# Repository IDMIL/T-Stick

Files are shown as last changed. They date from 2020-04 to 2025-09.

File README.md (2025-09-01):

# T-Stick Digital Musical Instrument (DMI)

The T-Stick is a DMI conceived by Joseph Malloch and D. Andrew Stewart at the Input Devices and Music Interaction Laboratory (IDMIL) at McGill University. It has been in development since 2006, has a relatively long history for a DMI, has multiple versions, several expert performers, and has an associated repertoire. More than 20 copies have been built unintended for commercial use. Nevertheless, it has been adopted by expert performers and composers as part of their musical practice including D. Andrew Stewart (Soprano user) and Fernando Rocha (Tenor user). It has appeared in dozens of public appearances in countries such as Canada, USA, Brazil, Italy, Norway, and Portugal.

This repository hosts up to date firmware for the T-Stick instruments currently at the IDMIL. The T-Stick Documentation data contains technical information as well as guides for how to use the T-Stick 4G/5G.

T-Stick Documentation: https://idmil.github.io/tstick-docs/

## Documentation:

[T-Stick connection guide for T-Stick 4G/5G](https://idmil.github.io/tstick-docs/designs/tstick-5gw/connection-guide/)

[T-Stick firmware upgrade guide](https://idmil.github.io/tstick-docs/designs/tstick-5gw/flashing-guide/)

[How to build a T-Stick 4G](https://idmil.github.io/tstick-docs/designs/tstick-5gw/build-guide/)

[How to build a T-Stick 5G](https://idmil.github.io/tstick-docs/designs/tstick-5gw/build-guide/)

[OSC sensor data list for T-Stick 4G/5G](https://idmil.github.io/tstick-docs/designs/tstick-5gw/specs_5gw_trill/#osc-signal-namespace)

## Instruments:

As of October 2021, there are over 20 instruments built at [IDMIL](http://www.idmil.org) and in use by several composers and performers:

- 01 T-Stick Tenor (2G)
- 06 T-Stick Sopranos (2G, 2GX, 2G-IMU)
- 01 T-Stick Sopranino (2G)
- 20+ wireless T-Stick Sopraninos (2G, 2GW, 3G, 4G, 5G)

## Project info:

Project webpage at IDMIL: http://www.idmil.org/project/the-t-stick/ \
T-Stick Documentation: https://idmil.github.io/tstick-docs/ \
Official repository: https://github.com/IDMIL/TStick

IDMIL - Input Devices and Music Interaction Laboratory - http://www.idmil.org/ \
CIRMMT - Centre for Interdisciplinary Research in Music Media and Technology - http://www.cirmmt.org/ \
Schulich School of Music - McGill University

## Licensing

The code in this project is licensed under the MIT license.

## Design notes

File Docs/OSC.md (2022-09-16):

# T-Stick OSC sensor data

## firmware 220916

#### (Replace XXX for the T-Stick ID number)

## Raw data

/TStick_XXX/raw/capsense, i..., 0--255, ... (1 int per 8 capacitive stripes -- 8 bits)

/TStick_XXX/raw/fsr, i, 0--4095

/TStick_XXX/raw/accl, fff, +/-24 (floats)

/TStick_XXX/raw/gyro, fff, +/-42 (floats)

/TStick_XXX/raw/magn, iii, +/-0.001 (floats)

## Instrument data

/TStick_XXX/instrument/button/count, i, 0--i

/TStick_XXX/instrument/button/tap, i, 0 or 1

/TStick_XXX/instrument/button/dtap, i, 0 or 1

/TStick_XXX/instrument/button/ttap, i, 0 or 1

/TStick_XXX/orientation, ffff, ?, ? ,? ,?

/TStick_XXX/instrument/ypr, fff, +/-180, +/-90 ,+/-180 (degrees)

/TStick_XXX/instrument/touch/all, f, 0--1

/TStick_XXX/instrument/touch/top, f, 0--1

/TStick_XXX/instrument/touch/middle, f, 0--1

/TStick_XXX/instrument/touch/bottom, f, 0--1

/TStick_XXX/instrument/brush, f, 0--? (~cm/s)

/TStick_XXX/instrument/multibrush, ffff, 0--? (~cm/s)

/TStick_XXX/instrument/rub, f, 0--? (~cm/s)

/TStick_XXX/instrument/multirub, ffff, 0--? (~cm/s)

/TStick_XXX/instrument/shakexyz, fff, 0--?

/TStick_XXX/instrument/jabxyz, fff, 0--?

/TStick_XXX/battery

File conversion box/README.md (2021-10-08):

# T-Stick Conversion Box - Building recipe - Rpi 2B and 3B+

Under Raspbian Lite

## Prepare the OS

- Flash the latest Prynth image (https://prynth.github.io/create/downloads.html)
- Add ssh file to Boot partition: `touch ssh`
- Add wpa_supplicant.conf to file to Boot partition: `vim wpa_supplicant.conf`. File contents:

```bash
ctrl_interface=DIR=/var/run/wpa_supplicant GROUP=netdev
update_config=1
country=US

network={
     ssid="Your network name/SSID"
     psk="Your WPA/WPA2 security key"
     key_mgmt=WPA-PSK
}
```

- Open Prynth software settings at `http://raspberrypi.local:3000/system` and change hostname to match the converted T-Stick  
- SSH, change password, hostname, set country, expand file system (raspi-config)

## Update

```bash
sudo apt-get -y update
sudo apt-get -y dist-upgrade
```

## Install liblo

```bash
sudo apt-get remove -y liblo-dev
mkdir ~/sources
cd ~/sources
git clone https://github.com/radarsat1/liblo.git
cd liblo
sudo apt-get install -y vim autoconf libtool automake
./autogen.sh
make
sudo make install
```

## Install Libmapper

```bash
sudo apt-get install python-dev swig
cd ~/sources
git clone https://github.com/libmapper/libmapper.git
cd libmapper
./autogen.sh
echo 'export LD_LIBRARY_PATH=$LD_LIBRARY_PATH:/usr/local/lib' >> ~/.bashrc
make
sudo make install
```

## Install Webmapper

```bash
pip install netifaces
cd ~/sources
git clone https://github.com/libmapper/webmapper.git
cp ~/sources/libmapper/swig/_mapper.so ~/sources/webmapper
cp ~/sources/libmapper/swig/mapper.py ~/sources/webmapper
cd webmapper/
```

- To run Webmapper: ./webmapper.py

## Install Python 3.7.3

```bash
sudo apt-get install -y build-essential tk-dev libncurses5-dev libncursesw5-dev libreadline6-dev libdb5.3-dev libgdbm-dev libsqlite3-dev libssl-dev libbz2-dev libexpat1-dev liblzma-dev zlib1g-dev libffi-dev apt-show-versions
cd ~/sources
wget https://www.python.org/ftp/python/3.7.3/Python-3.7.3.tgz
tar -zxvf Python-3.7.3.tgz
cd Python-3.7.3/
./configure --enable-optimizations
make -j4
make test
sudo make install
```

Reboot

## Create python application to read serial port and send OSC messages

- Install packages:

```bash
cd ~
sudo apt-get install -y python3-pip python-pip setserial
sudo pip3 install python-osc pyserial apscheduler bitstring netifaces
pip install pyserial apscheduler bitstring pyOSC netifaces oscpy
mkdir tstick
```

- Create code:

```bash
cat <<- "EOF" | sudo tee ~/tstick/tstick.py
# Python code to convert T-Stick serial port messages to OSC
# Author: Edu Meneses (IDMIL, 2019)

import sys
import serial
import collections
from apscheduler.schedulers.background import BackgroundScheduler
from bitstring import BitArray
import netifaces as ni

import argparse
from pythonosc import osc_message_builder
from pythonosc import udp_client
from pythonosc.dispatcher import Dispatcher

from pythonosc.osc_server import AsyncIOOSCUDPServer
import asyncio

# parse argument to set OSC to send/receive T-Stick data
parser = argparse.ArgumentParser(
    description='Convert T-Stick serial port messages into OSC messages.',
    formatter_class=argparse.ArgumentDefaultsHelpFormatter)
parser.add_argument("--serialport", "-s", default="/dev/ttyUSB0",
                    metavar='', help="The T-Stick's serial port")
parser.add_argument("--ip", "-i", default="192.168.0.1",
                    metavar='', help="The ip of the OSC server")
parser.add_argument("--port", "-p", type=int, default=8000,
                    metavar='', help="The port the OSC server is listening on")
parser.add_argument("--networkinterface", "-n", default="wlan0",
                    metavar='', help="The interface connected to the network")
parser.add_argument("--listenport", "-l", type=int, default=8888,
                    metavar='', help="The port this machine is listening on")
args = parser.parse_args()

# set listening ip to receive OSC messages
ni.ifaddresses(args.networkinterface)
local_ip = ni.ifaddresses(args.networkinterface)[ni.AF_INET][0]['addr']

# Opening T-Stick serial port
tstick = serial.Serial(args.serialport, 115200, dsrdtr=1)

# checking system byteorder
byteorder = sys.byteorder

# creating global variable to define T-Stick mapping
tstick_id = 0

dispatcher = Dispatcher()

client_OSC = udp_client.SimpleUDPClient(args.ip, args.port)

def resend(address, *args):
    tstick.write(args)

def heartbeat():
    tstick.write('s'.encode('utf-8'))

async def receive_serial():
    flag = False
    msg = []
    while True:
        byte = int.from_bytes(tstick.read(), byteorder)
        if not flag:
            if byte == 100:
                get_tstick_id(*msg)
                if(tstick_id == 173):
                    sort_and_send_173(*msg)
                elif(tstick_id == 10 or
                     tstick_id == 12 or
                     tstick_id == 24 or
                     tstick_id == 171):
                    sort_and_send_2G(*msg)
                elif(tstick_id == 15):
                    sort_and_send_2GX(*msg)
                msg.clear()
            elif byte == 101:
                flag = True
            else:
                msg.append(byte)
        else:
            msg.append(byte)
            flag = False
        await asyncio.sleep(0)

# 'convert' 10 bits
def bit_conversion(byte1, byte2):
    return (byte1 * 256) + byte2

# T-stick 16 bit conversion IMU
def bit_ext_conversion(byte1, byte2):
    bin_or = (byte1 * 256) | byte2
    return bin_or - (65535 * (bin_or > 32767))

def get_tstick_id(*msg):
    if msg[0] == 0:
        if len(msg) < 3:
            return 0
        global tstick_id
        tstick_id = bit_conversion(msg[1], msg[2])
        firmware = bit_conversion(msg[3], msg[4])
        info_list = [tstick_id, firmware]
        if len(msg) > 5:
            for i in msg[5:]:
                info_list.append(i)
        client_OSC.send_message("/information", info_list)
        return tstick_id

# route T-Stick messages for T-Stick #173
def sort_and_send_173(*msg):
    if msg[0] == 0:
        pass
    elif msg[0] == 1:
        rawcapsense = msg[1:]
        client_OSC.send_message("/rawcapsense", rawcapsense)
        # capsense_bits = cook_touch_soprano(*rawcapsense)
    elif msg[0] == 2:
        accel_x = bit_ext_conversion(msg[1], msg[2])
        accel_y = bit_ext_conversion(msg[3], msg[4])
        accel_z = bit_ext_conversion(msg[5], msg[6])
        gyro_x = bit_ext_conversion(msg[7], msg[8])
        gyro_y = bit_ext_conversion(msg[9], msg[10])
        gyro_z = bit_ext_conversion(msg[11], msg[12])
        pressure = bit_ext_conversion(msg[13], msg[14])
        piezo = bit_ext_conversion(msg[15], msg[16])
        client_OSC.send_message("/rawaccel", [accel_x, accel_y, accel_z])
        client_OSC.send_message("/rawgyro", [gyro_x, gyro_y, gyro_z])
        client_OSC.send_message("/rawpressure", pressure)
        client_OSC.send_message("/rawpiezo", piezo)
    elif msg[0] == 3:
        mag_x = bit_ext_conversion(msg[1], msg[2])
        mag_y = bit_ext_conversion(msg[3], msg[4])
        mag_z = bit_ext_conversion(msg[5], msg[6])
        client_OSC.send_message("/rawmag", [mag_x, mag_y, mag_z])
    elif msg[0] == 4:
        return 0

# route T-Stick messages for T-Stick 2G series: 010, 012, 024, 171
def sort_and_send_2G(*msg):
    if msg[0] == 0:
        pass
    elif msg[0] == 1:
        rawcapsense = msg[1:]
        client_OSC.send_message("/rawcapsense", rawcapsense)
        # capsense_bits = cook_touch_soprano(*rawcapsense)
    elif msg[0] == 2:
        rawjab = msg[1:]
        client_OSC.send_message("/rawjab", rawjab)
    elif msg[0] == 3:
        rawtap = msg[1:]
        client_OSC.send_message("/rawtap", rawtap)
    elif msg[0] == 4:
        accel_x = bit_conversion(msg[1], msg[2])
        accel_y = bit_conversion(msg[3], msg[4])
        accel_z = bit_conversion(msg[5], msg[6])
        pressure = bit_conversion(msg[7], msg[8])
        piezo = bit_conversion(msg[9], msg[10])
        client_OSC.send_message("/rawaccel", [accel_x, accel_y, accel_z])
        client_OSC.send_message("/rawpressure", pressure)
        client_OSC.send_message("/rawpiezo", piezo)

# route T-Stick messages for T-Stick #015
def sort_and_send_2GX(*msg):
    if msg[0] == 0:
        pass
    elif msg[0] == 1:
        rawcapsense = msg[1:]
        client_OSC.send_message("/rawcapsense", rawcapsense)
        # capsense_bits = cook_touch_soprano(*rawcapsense)
    elif msg[0] == 2:
        rawjab = msg[1:]
        client_OSC.send_message("/rawjab", rawjab)
    elif msg[0] == 3:
        rawtap = msg[1:]
        client_OSC.send_message("/rawtap", rawtap)
    elif msg[0] == 4:
        accel_x = bit_conversion(msg[1], msg[2])
        accel_y = bit_conversion(msg[3], msg[4])
        accel_z = bit_conversion(msg[5], msg[6])
        pressure = bit_conversion(msg[7], msg[8])
        piezo = bit_conversion(msg[9], msg[10])
        airpressure = bit_conversion(msg[11], msg[12])
        tstick_range = bit_conversion(msg[13], msg[14])
        ldr1 = bit_conversion(msg[15], msg[16])
        ldr2 = bit_conversion(msg[17], msg[18])
        client_OSC.send_message("/rawaccel", [accel_x, accel_y, accel_z])
        client_OSC.send_message("/rawpressure", pressure)
        client_OSC.send_message("/rawpiezo", piezo)
        client_OSC.send_message("/rawairpressure", airpressure)
        client_OSC.send_message("/rawrange", tstick_range)
        client_OSC.send_message("/rawldr1", ldr1)
        client_OSC.send_message("/rawldr2", ldr2)

# make bit list - 1 per cap stripe
def cook_touch_soprano(*bytes):
    byte_list = ""
    for byte in bytes:
        byte_list = byte_list + format(byte, '08b')
    return list(byte_list)

# setting heartbeat to run every second
def tstick_wakeup():
    scheduler = BackgroundScheduler()
    scheduler.add_job(heartbeat, 'interval', seconds=1)
    scheduler.start()

async def init_main():
    # Create datagram endpoint and start serving
    server_OSC = AsyncIOOSCUDPServer(
        (local_ip, args.listenport), dispatcher, asyncio.get_event_loop())

    transport, protocol = await server_OSC.create_serve_endpoint()

    dispatcher.map("/status", resend)

    tstick_wakeup()

    await receive_serial()

    transport.close()  # Clean up serve endpoint

    sys.exit()

asyncio.run(init_main())  # Init and enter main loop of program

EOF

```
Set the code to load at boot:

```bash
cat <<- "EOF" | sudo tee /lib/systemd/system/tstick.service
[Unit]
Description=T-Stick serial port to OSC conversion

[Service]
ExecStart=/usr/bin/python3 /home/pi/tstick/tstick.py
#User=pi

[Install]
WantedBy=multi-user.target
EOF

```

```bash
sudo systemctl daemon-reload &&\
sudo systemctl enable hardwarecontrol.service
```

Old, unnecessary packages are removed after the system update with the following commands:

```bash
sudo apt-get autoremove
sudo apt-get autoclean
```

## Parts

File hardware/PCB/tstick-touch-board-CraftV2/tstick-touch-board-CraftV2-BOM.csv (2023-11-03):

Manufacturer | Manufacturer Part # | Qty | Description Value Pkg | Reference(s)
Molex | 54132-3262 | 1 | 32 Position FFC, FPC Connector Contacts, Bottom 0.020" (0.50mm) Surface Mount, Right Angle | J1
JST Sales America Inc. | BM04B-SRSS-TB | 4 | Connector Header Surface Mount, Right Angle 4 position 0.039" (1.00mm) | I2C1,I2C2,INT1,INT2

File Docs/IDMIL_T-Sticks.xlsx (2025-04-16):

Update: | 2025-03-11
ID | Model | Generation | FirmWare | Last Review | Pictures |  |  | Comments | Status
191 | Sopranino |  |  |  |  |  |  |  | IDMIL
193 | Sopranino | 4 | TBC |  | #VALUE! | #VALUE! | #VALUE! | turns on as 001 flow of OSC messages very slow ~1/s button and switch don't seem to do anything works only when plugged | Location unknown
194 | Sopranino | 4 | TBC | 2024-08-31 | #VALUE! | #VALUE! | #VALUE! | Unclear which if for on/off or charging (switch or button) No light turning on, no OSC message received hear a loose piece inside | Location unknown
308 | Sopranino | 4 | TBC | 2024-08-31 | #VALUE! | #VALUE! | #VALUE! | Several capsense tend to stay stuck Capsense # 16 never turn on shake values can go from ~0.8 to > 200 jabs triggered at the slightest movement | Location unknown
311 | Sopranino | 4 | TBC |  | #VALUE! | #VALUE! | #VALUE! |  | IDMIL
315 | Soprano | ? |  |  |  |  |  | USB connection is loose need reflash? Needs to be plugged to work | IDMIL
500 | Sopranino | 5 |  |  |  |  |  | button doesn't work Oren's haptic T-Stick? | IDMIL
514 | Sopranino | 5 |  |  | #VALUE! | #VALUE! |  | Turns off for ~5s when strongly shaken… Needs maintenance | IDMIL
516 |  |  |  |  |  |  |  | FSR doesn't work capsense values up to 1000+??? | IDMIL
517 | Sopranino | 5 |  |  |  |  |  | Don't know if it can be glued back | Borrowed by GM
555 | Sopranino | 5 |  |  |  |  |  | seems ok… | IDMIL
566 | Sopranino | 5 |  |  |  |  |  | Capsense doesn't work | Location unknown
569 | Sopranino | 5 |  |  |  |  |  | doesn't turn on | IDMIL
588 |  |  |  |  |  |  |  | unlabeled prototype | IDMIL

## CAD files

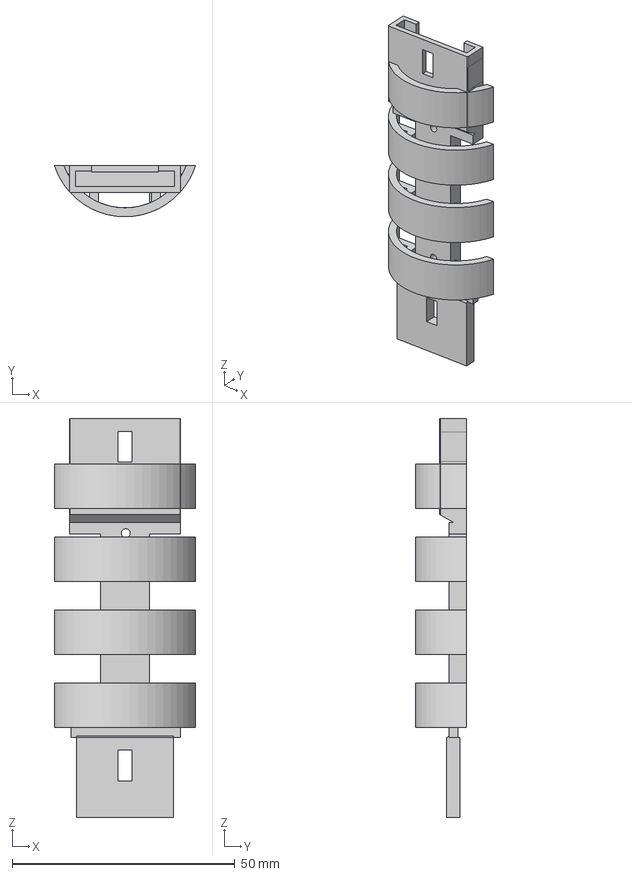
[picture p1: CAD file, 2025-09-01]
3D_printing/T-Stick 4GW/bed_capsense.stp
31.7 x 11.5 x 89.5 mm
battery_cap
esp_cap
capsense_bed+arcs
dummy_bed+arcs x 2
tinypico + imu_bed+arcs (1)
poles
small pin (1)

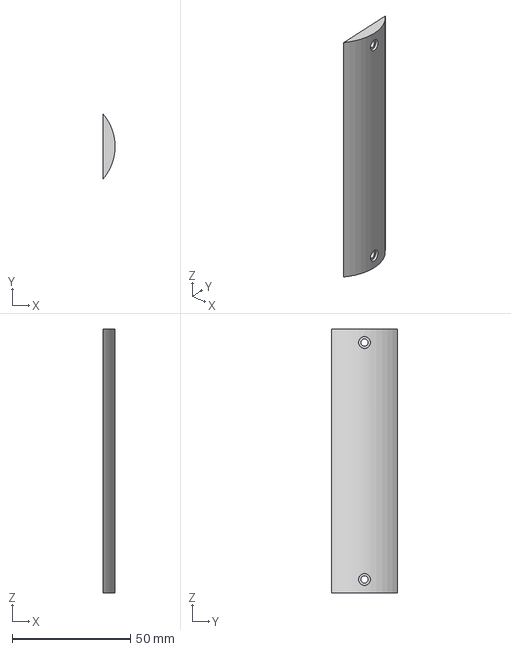
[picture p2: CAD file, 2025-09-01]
3D_printing/T-Stick 5GW/touch-board-door.step
5.19 x 27.7 x 111.4 mm

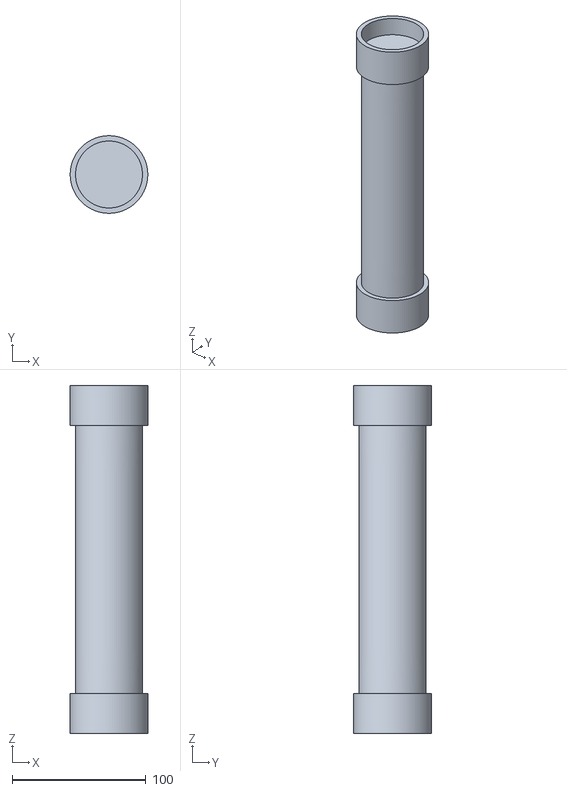
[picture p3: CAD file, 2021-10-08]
Sopranino/2GW/FW19111/Configuration/T-Stick.stl
58.0 x 58.0 x 260.0

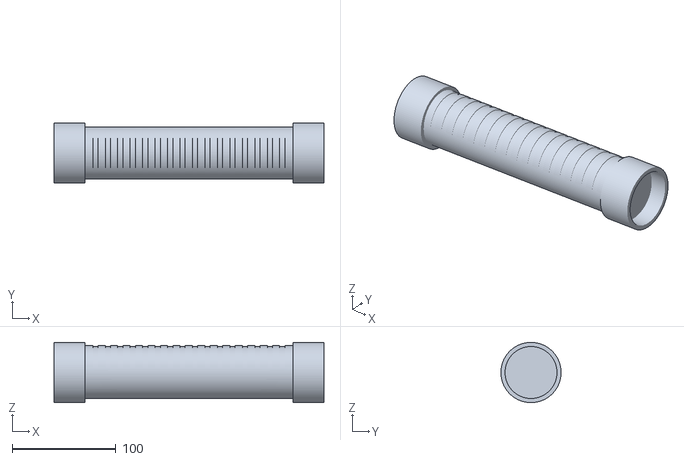
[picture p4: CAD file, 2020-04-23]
Test_config/PD/T-Stick.stl
260.0 x 58.0 x 58.0

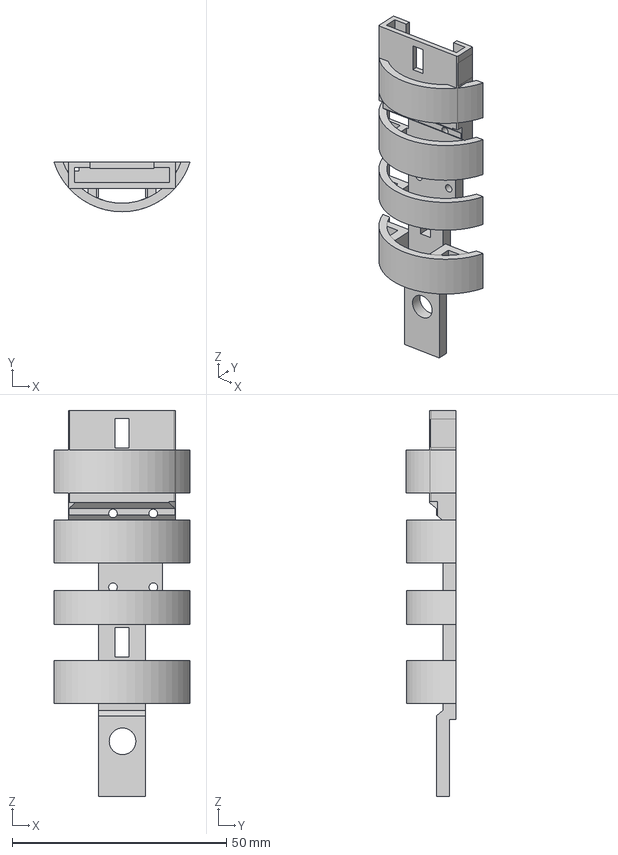
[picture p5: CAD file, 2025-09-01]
3D_printing/T-Stick 4GW/bed_tinypico_microUSB.stp
31.7 x 11.5 x 90.0 mm
battery_cap
esp_cap
capsense_bed+arcs
dummy_bed+arcs x 2
tinypico + imu_bed+arcs (1)
poles
small pin (1)

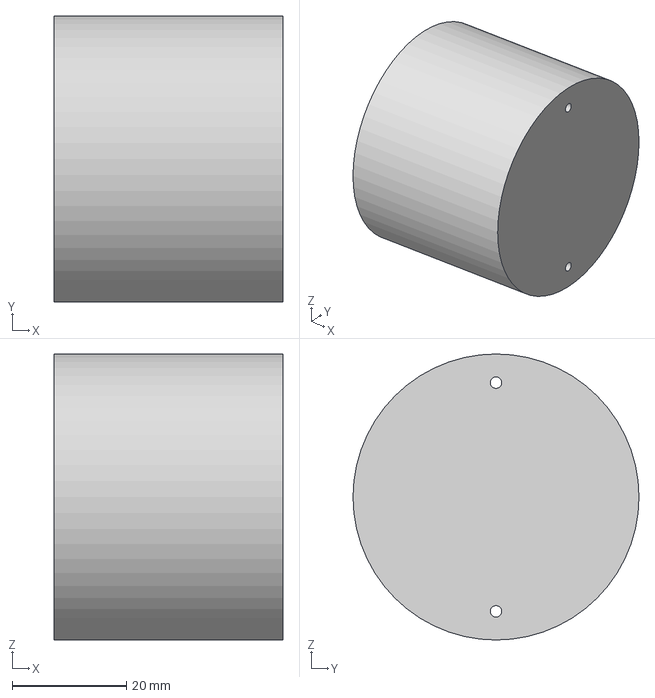
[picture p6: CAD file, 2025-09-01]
3D_printing/T-Stick 5GW/liion-capcloser.step
40.0 x 50.0 x 50.0 mm

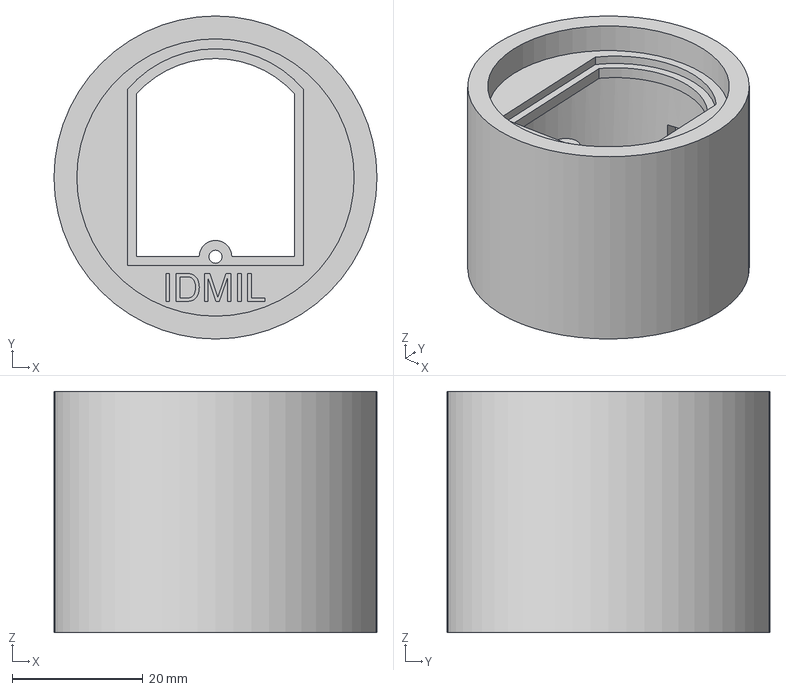
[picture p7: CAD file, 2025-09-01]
3D_printing/T-Stick 4GW/cap_battery_body.stp
49.5 x 49.5 x 37.0 mm
battery_cap
esp_cap
capsense_bed+arcs
dummy_bed+arcs x 2
tinypico + imu_bed+arcs (1)
poles
small pin (1)

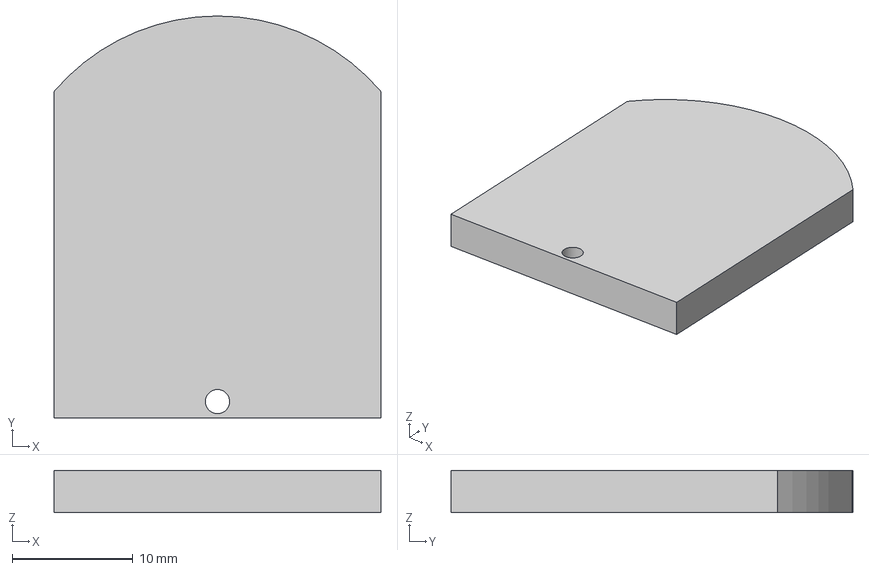
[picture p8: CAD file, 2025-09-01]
3D_printing/T-Stick 4GW/cap_battery_cover.stp
27.0 x 33.2 x 3.50 mm
battery_cap
esp_cap
capsense_bed+arcs
dummy_bed+arcs x 2
tinypico + imu_bed+arcs (1)
poles
small pin (1)

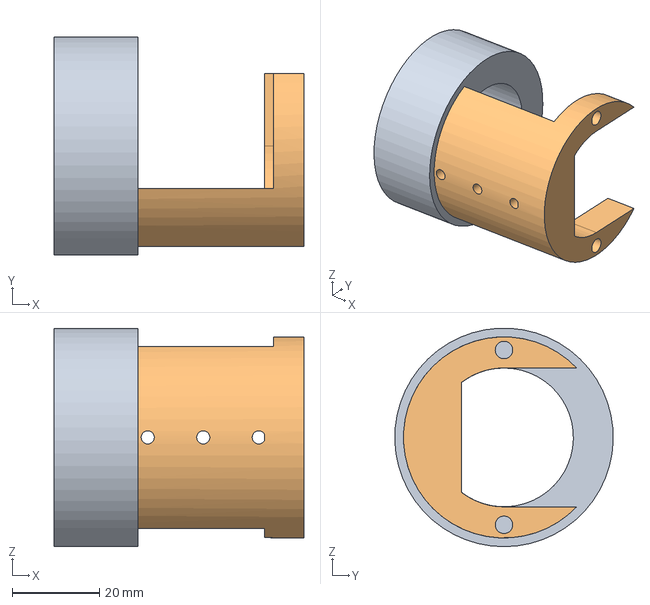
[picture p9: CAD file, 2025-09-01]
3D_printing/T-Stick 5GW/liion-endcap.step
57.2 x 50.0 x 50.0 mm
pvc-connector
main-body

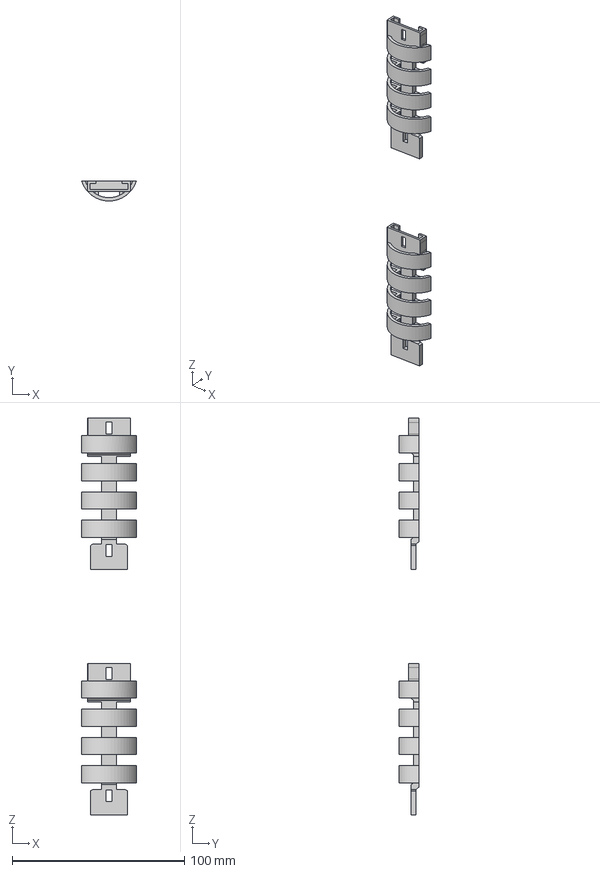
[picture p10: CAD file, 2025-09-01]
3D_printing/T-Stick 4GW/bed_dummy.stp
31.7 x 11.7 x 230.5 mm
battery_cap
esp_cap
capsense_bed+arcs
dummy_bed+arcs x 2
tinypico + imu_bed+arcs (1)
poles
small pin (1)

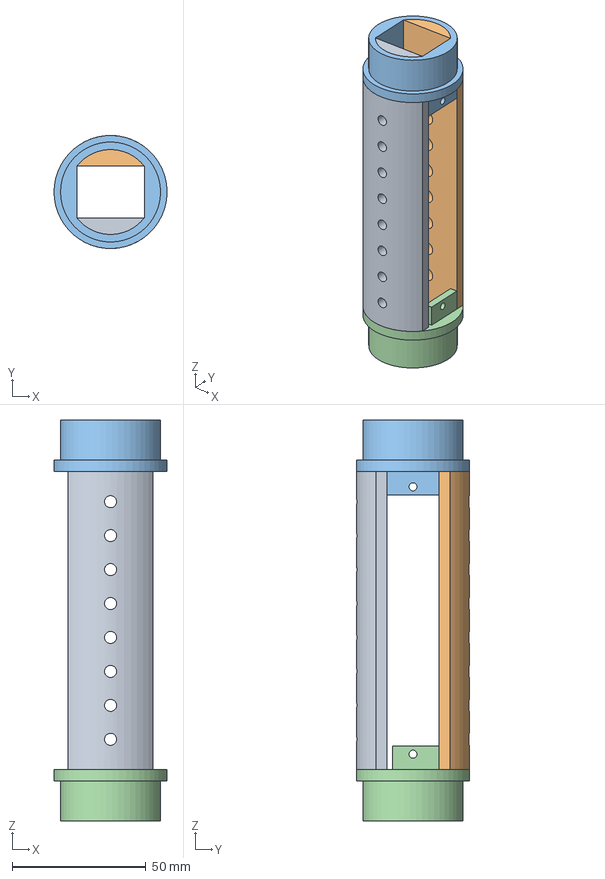
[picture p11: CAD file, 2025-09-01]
3D_printing/T-Stick 5GW/touch-board-bed.step
42.3 x 42.3 x 150.0 mm
touch-board-bed_1
touch-board-top
inner-connector

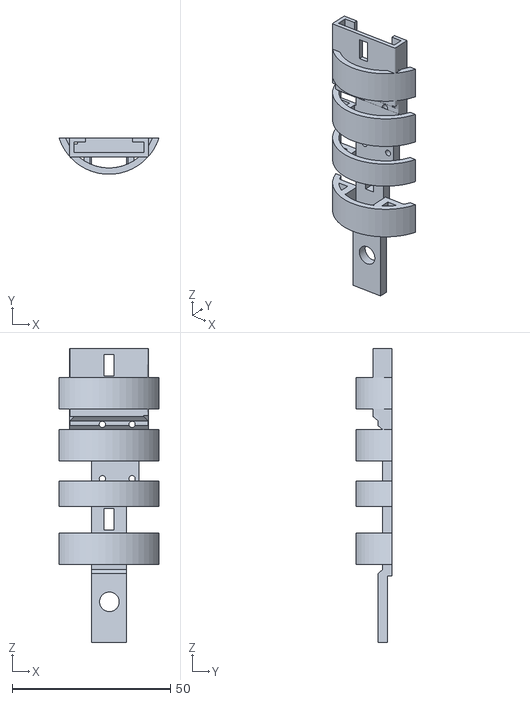
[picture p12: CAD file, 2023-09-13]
3D_printing/T-Stick 4GW/bed_tinypico_usbc.stl
31.7 x 11.5 x 93.0

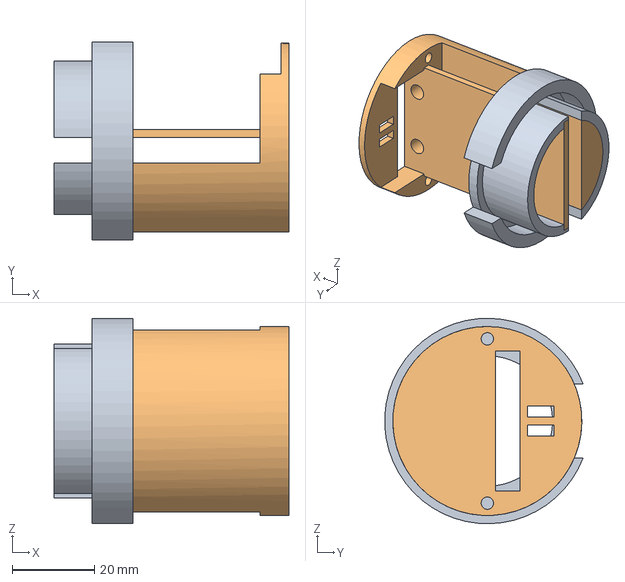
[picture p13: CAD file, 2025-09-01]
3D_printing/T-Stick 5GW/esp32-endcap.step
57.2 x 48.3 x 50.0 mm
pvc-connector
main-body

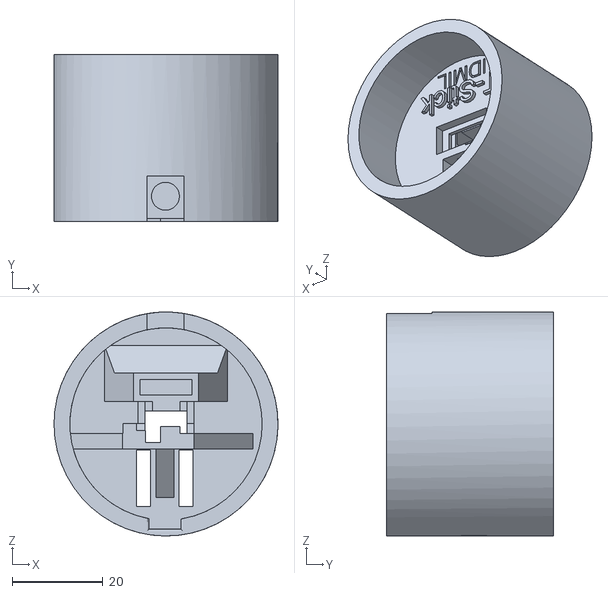
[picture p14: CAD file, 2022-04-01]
3D_printing/T-Stick 4GW/cap_tinypico_microUSB.stl
49.5 x 37.0 x 49.5

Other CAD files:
3D_printing/T-Stick 5GW/esp32-capcloser.step
3D_printing/T-Stick 5GW/blank-endcap.step
3D_printing/T-Stick 4GW/pole.stl
3D_printing/T-Stick 4GW/cap_tinypico_USBC.stl
3D_printing/T-Stick 4GW/bed_Trill.stl
3D_printing/T-Stick 4GW/bed_tinypico_microusb.stl
3D_printing/T-Stick 4GW/pin_scaled_0.99.stl
3D_printing/T-Stick 4GW/pole_tinypico.stl
Sopranino/2GW/FW19111/Configuration/T-Stick.f3d
Test_config/PD/T-Stick.f3d

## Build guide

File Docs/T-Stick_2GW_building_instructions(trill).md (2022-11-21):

# Building a Sopranino T-Stick (v1.2)

## Bill of Materials

Qty   | Description
------|---------------------
01    | [Trill](https://shop.bela.io/products/trill-craft/)     
01    | [TinyPICO](https://www.adafruit.com/product/4335)        
01    | [IMU breakout board LSM9DS](https://www.sparkfun.com/products/13284)
01    | [FSR 408](https://www.robotshop.com/ca/en/interlink-24-long-fsr.html)
01    | 1K resistor
01    | [10K potentiometer](https://www.digikey.com/products/en?mpart=PV36W103C01B00&v=118)
01    | [button](https://www.digikey.ca/product-detail/en/c-k/PTS125SM43-2-LFS/CKN9100-ND/1146743)
01    | Li-Po Battery min 1000mA
01    | PVC Tube (30 cm)
~85cm | Copper adhesive tape
01    | [ON-OFF rocker switch](https://www.digikey.ca/product-detail/en/RA1113112R/EG5619-ND/3778055/?itemSeq=307636370)
~35cm | Heat shrink tube
01    | end-cup with microcontroller base
01    | end-cup with for the ON-OFF switch
01    | [3D printed bases](../3D_printing/), one of each file, and 4 regular poles
11    | [M2 Mounting Screws](https://www.digikey.ca/product-detail/en/MPMS+002+0008+PH/H739-ND/274950/?itemSeq=307635387)
01    | [foam sheet](https://www.amazon.ca/Craft-Foam-Sheets-Assorted-Colours/dp/B005EQPRM6)

## Instructions

### Printing the Frame

Print one of each of the [3d printing files](../3D_printing/), but print 4 copies of the "regular poles".
The beds (pieces that snap together) will need supports on the piece that snaps.

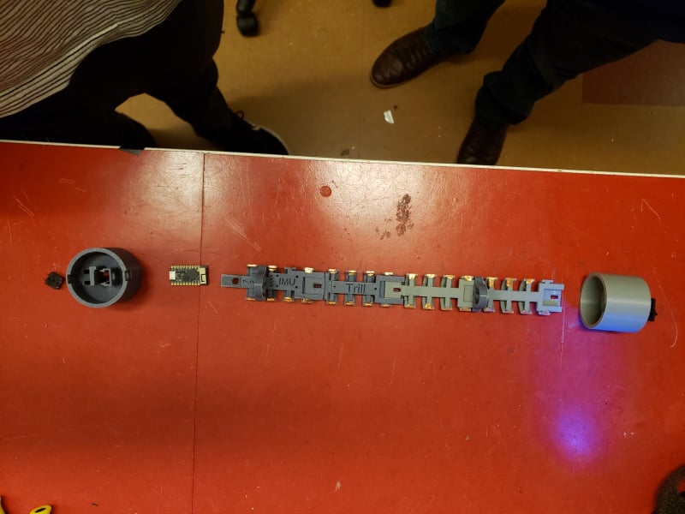
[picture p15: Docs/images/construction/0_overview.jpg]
Overview 3d printing overview


Snap the beds together as in the image above, snapping the regular poles between beds to secure them.
Place copper strips on each arc in the beds, these will be used for capacitive touch sensing.

### Soldering Components

All the building tools can be found in the Machine Shop at the McGill Music Tech Department.

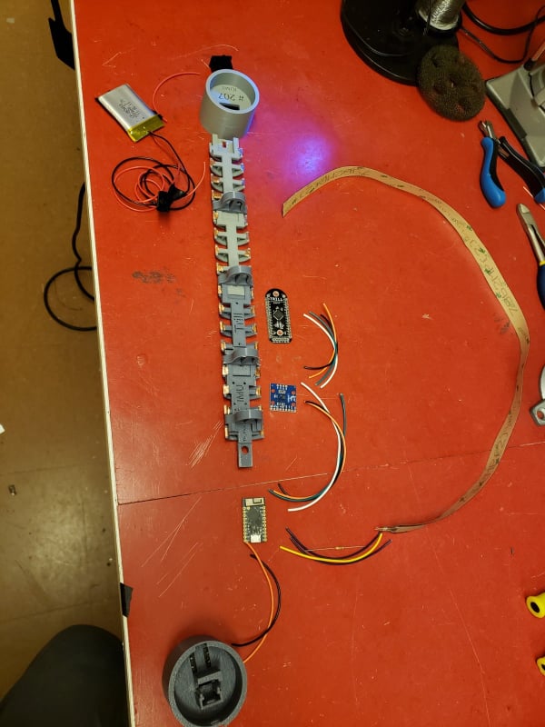
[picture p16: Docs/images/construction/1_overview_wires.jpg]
Overview_wires wiring overview


Let's start with the end cap where the TinyPICO will be inserted. Insert the button into the slot like the pictures below.

button top view| button bottom view | soldering
--- | --- | ---
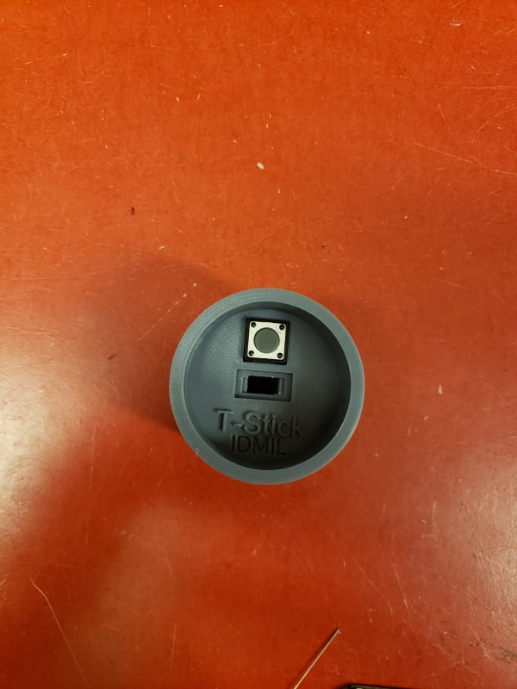
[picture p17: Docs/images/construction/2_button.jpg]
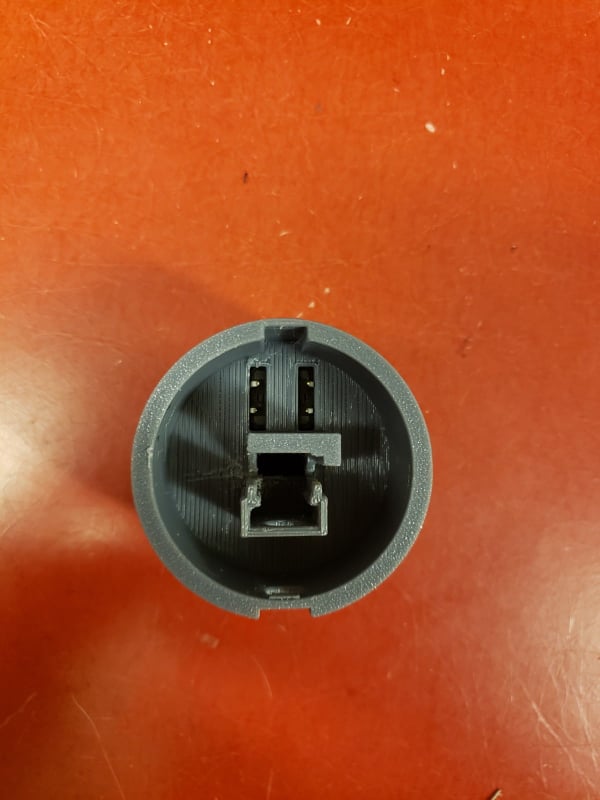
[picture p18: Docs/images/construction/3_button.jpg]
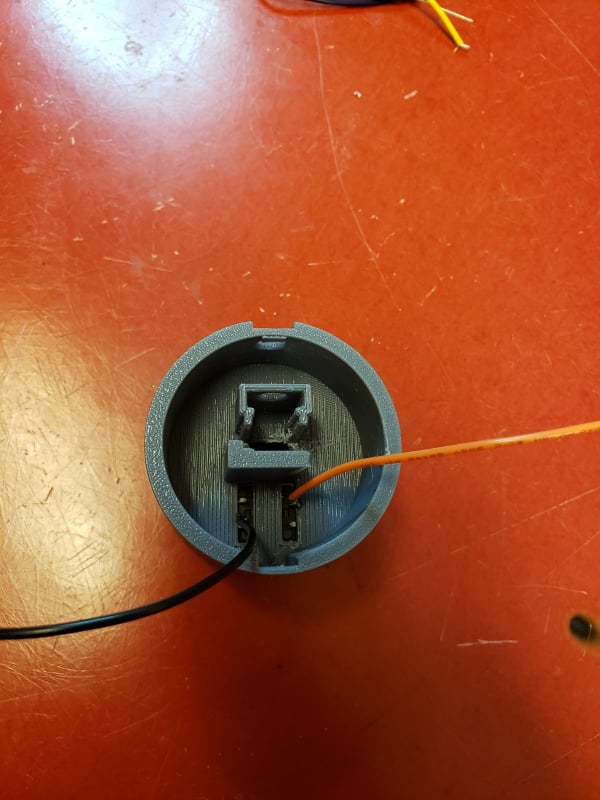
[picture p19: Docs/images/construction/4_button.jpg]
 |  | 

Solder 2 wires diagonally to the button pins, connecting one to GND and one to pin 15 on the TinyPICO. For the GND connection, twist an extra wire together before soldering to the TinyPICO, which will be used for connecting the IMU later on.

connecting to TinyPICO | completed button circuit
--- | ---
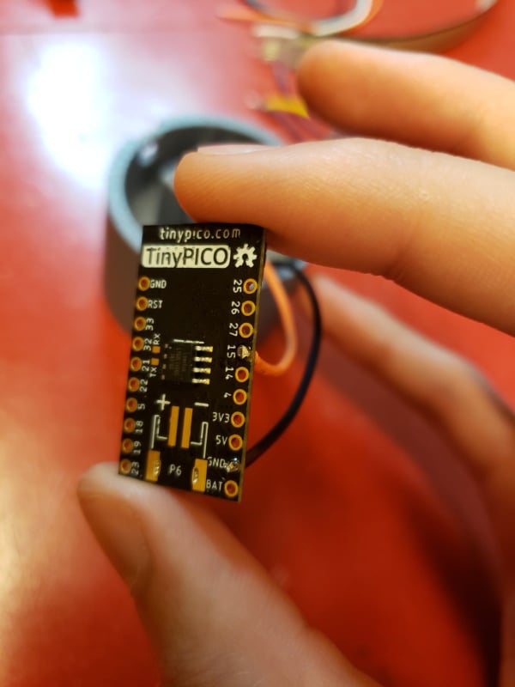
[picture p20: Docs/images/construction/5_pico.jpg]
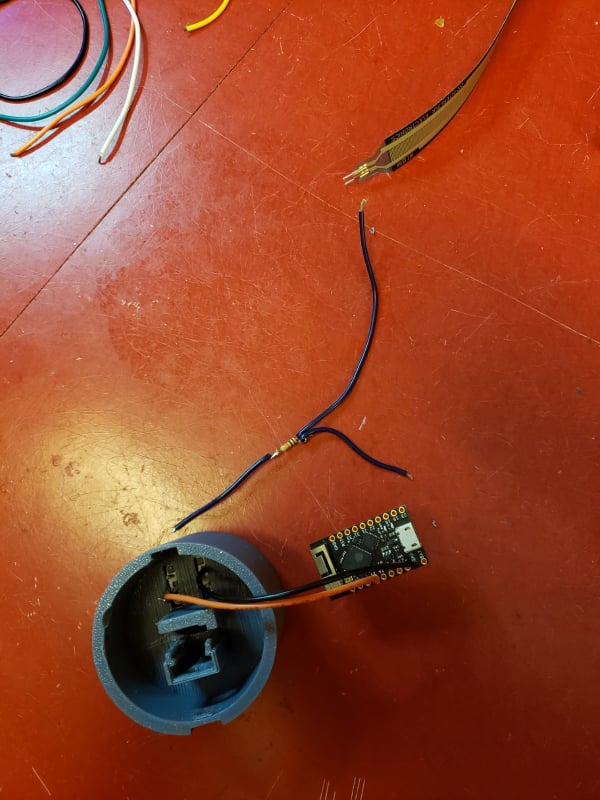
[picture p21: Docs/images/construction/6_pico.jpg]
 | 

To prepare the resistor for its FSR connection, solder 2 wires to one end and 1 to the other like below. Use heat shrink to wrap the connection. Solder the single end wire to a GND pin on the button. Solder one of the double end wires to pin 33 on the TinyPICO.

soldering | heat shrinking | connecting to TinyPICO
--- | --- | ---
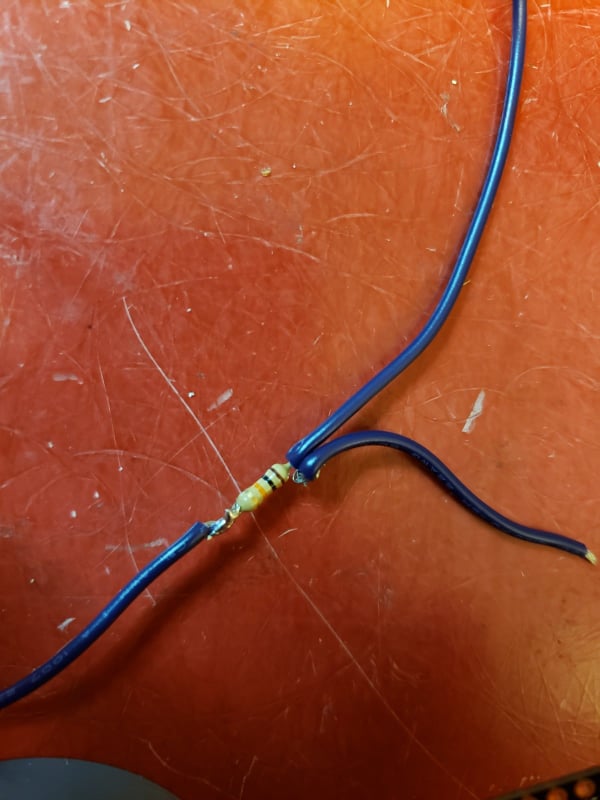
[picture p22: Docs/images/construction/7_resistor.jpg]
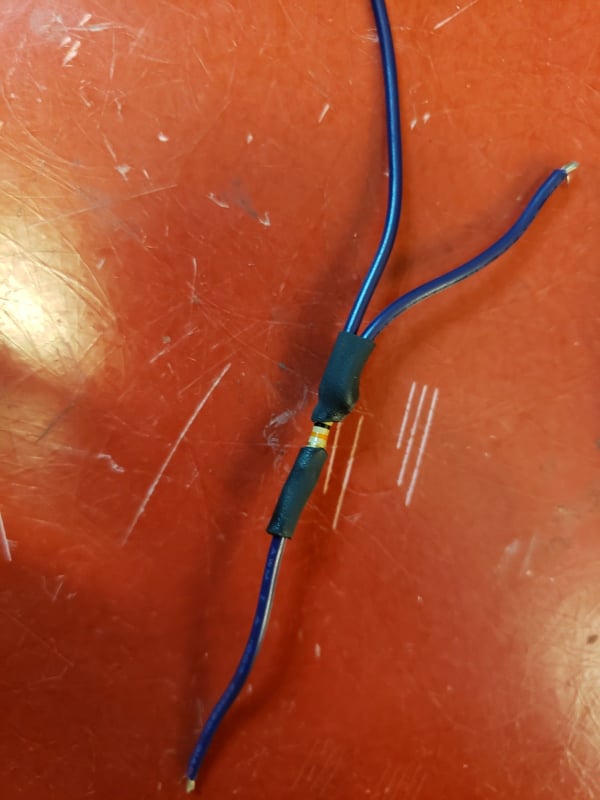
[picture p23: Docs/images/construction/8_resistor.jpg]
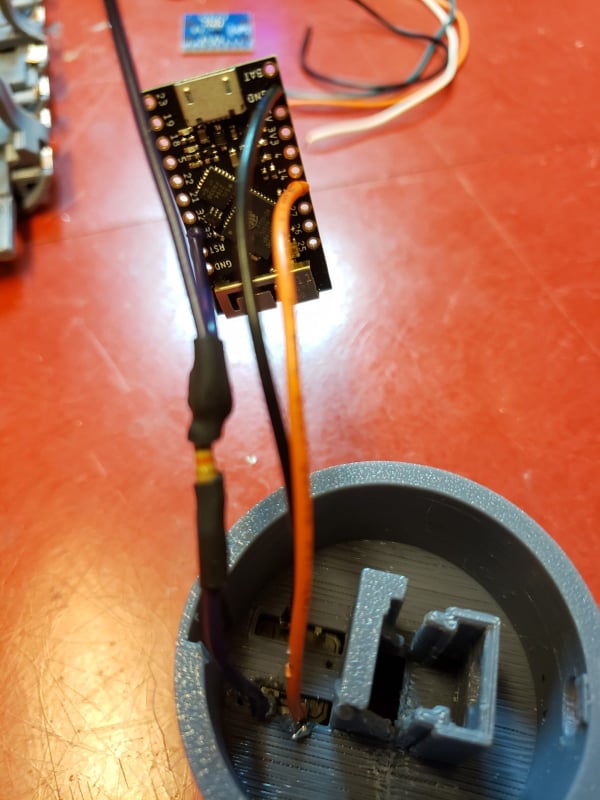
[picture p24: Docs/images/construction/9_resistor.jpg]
 |  | 

Prepare the FSR connections by carefully soldering 2 wires to its terminals, using the extra wire form the resistor as one of the terminals. Be cautious not to melt the plastic on the FSR if possible by soldering quickly. Heat shrink the terminals when complete. 

soldering | heat shrinking
--- | ---
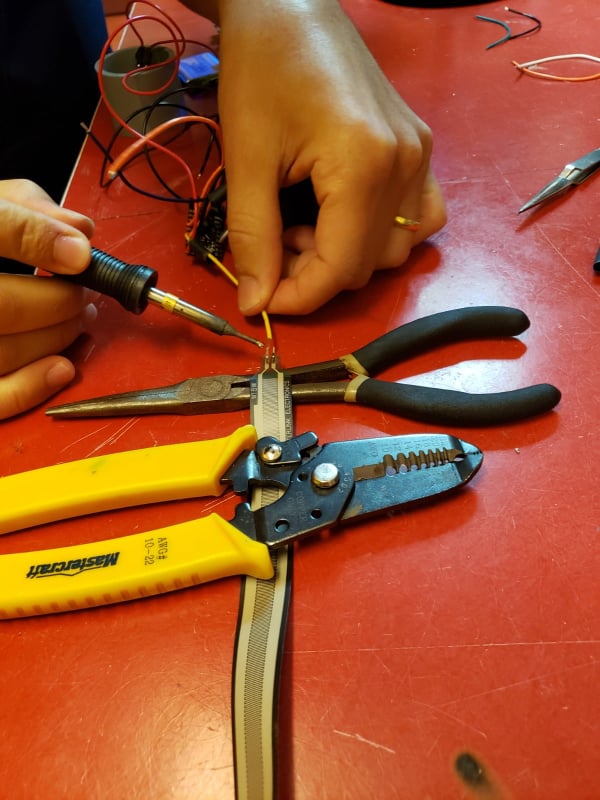
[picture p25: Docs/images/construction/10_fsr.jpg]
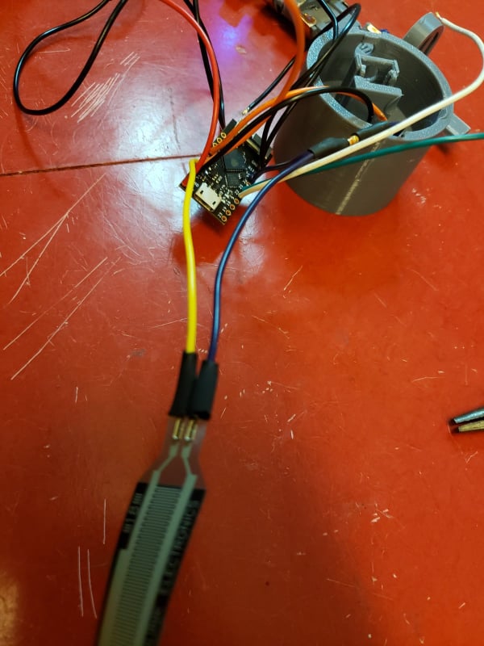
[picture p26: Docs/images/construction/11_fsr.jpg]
 | 

Solder the other FSR wire **and** another wire (which will connect to the IMU) to the 3V3 pin on the TinyPICO (yellow and orange in the picture below). Twisting the 2 wires together before inserting into the pin will make this task easier.

twisting and soldering | view of 3V3 pin
--- | ---
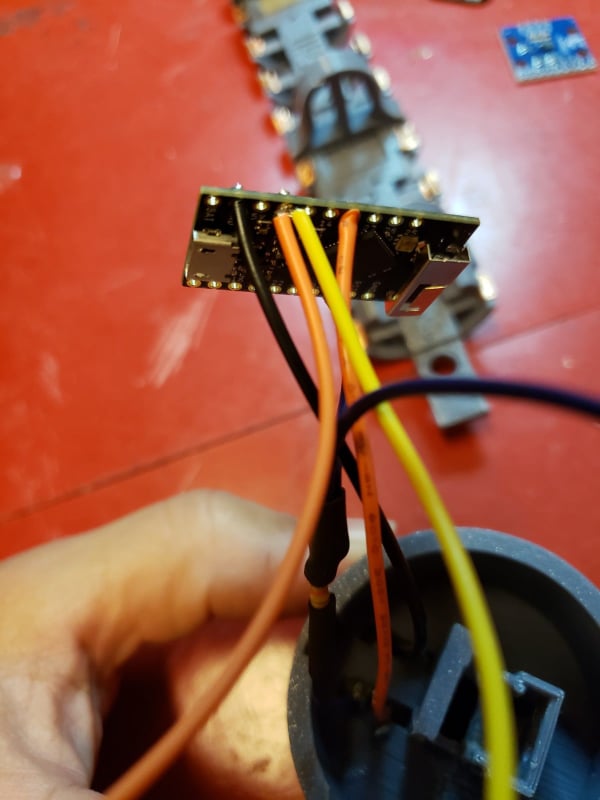
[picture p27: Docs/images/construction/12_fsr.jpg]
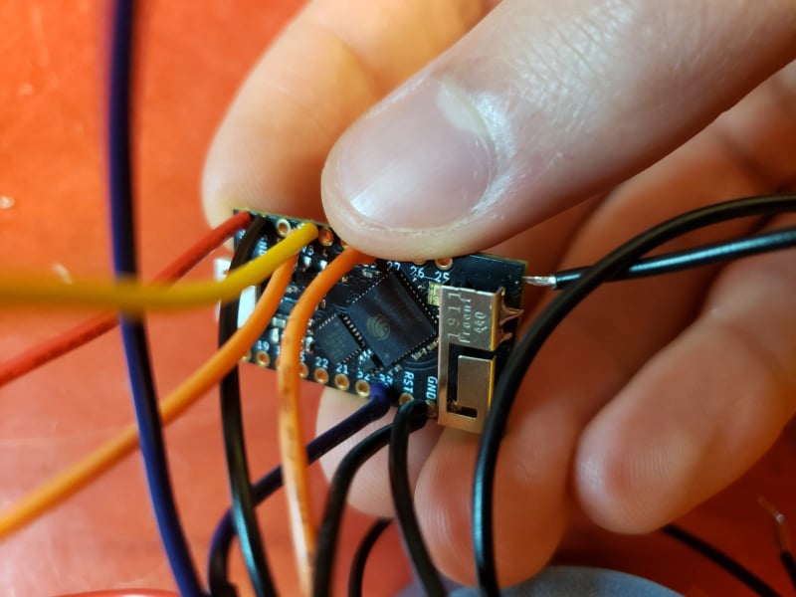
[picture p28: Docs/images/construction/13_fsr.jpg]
 | 

Solder 2 wires to each of the IMU's GND, VCC, SDA and SCL pins. One of the VCC wires and one of the GND wires should be the extra 3V3 and GND wires from the TinyPICO that you put in in the above steps. Connect one of the SDA wires to pin 21 of the TinyPICO, and one of the SCL wires to pin 22 of the TinyPICO. 

twisting and soldering | connecting to TinyPICO | imu wiring
--- | --- | ---
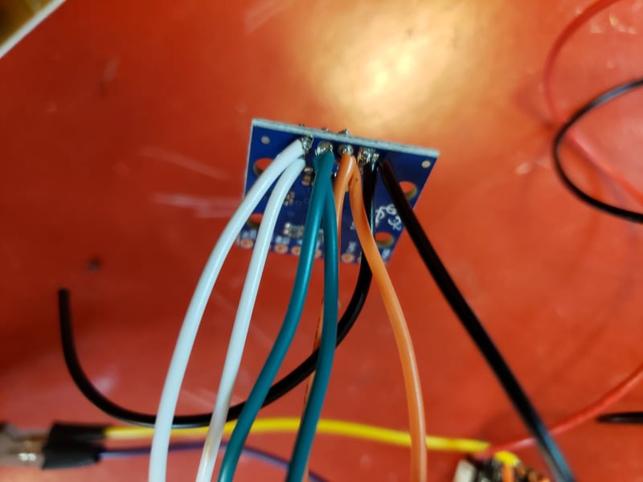
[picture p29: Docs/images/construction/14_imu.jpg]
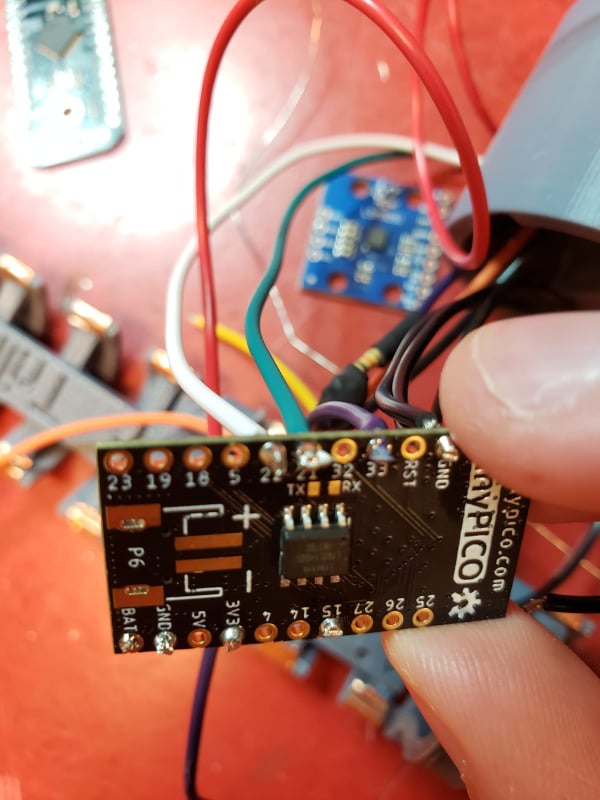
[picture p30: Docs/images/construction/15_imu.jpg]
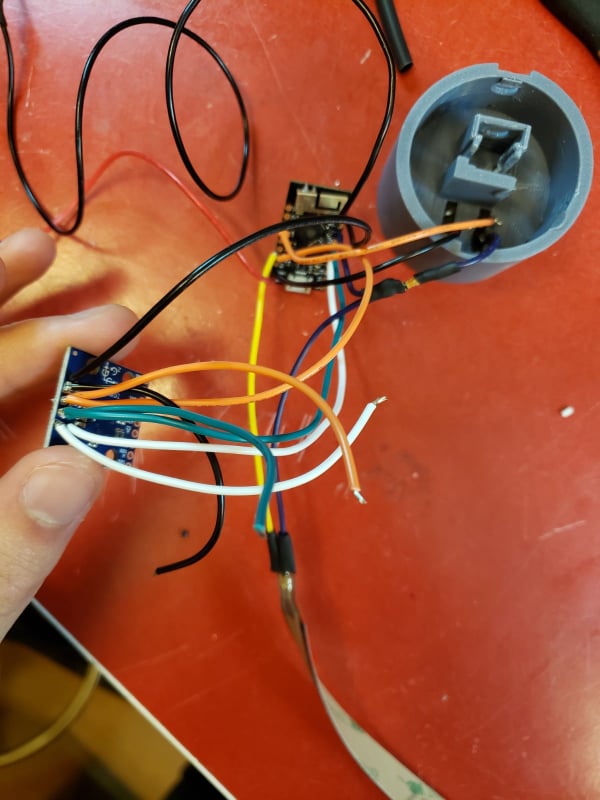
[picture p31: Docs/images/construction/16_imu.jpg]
 |  | 

At this stage, the IMU should have unconnected wires (1 of each) from SDA, SCL, GND and VCC. Run the 4 unconnected wires through the pole and solder to the corresponding labeled pins on the Trill.

trill connections | alternate view
--- | ---
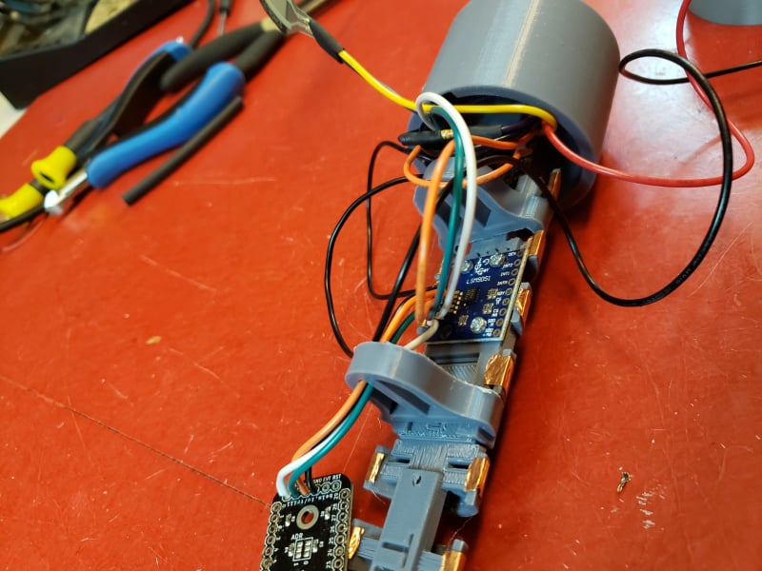
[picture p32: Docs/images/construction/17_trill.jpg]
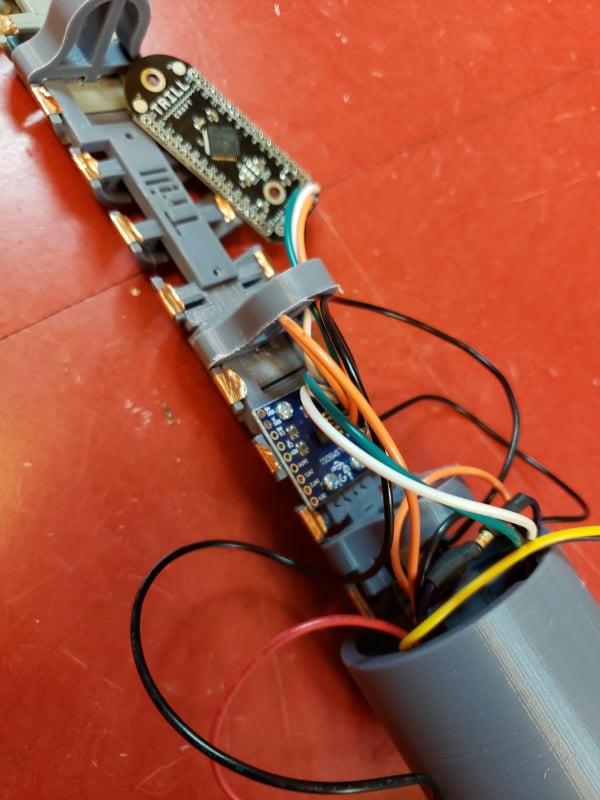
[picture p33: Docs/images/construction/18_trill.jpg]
 | 

Now for the fun part ;). Solder wires onto each of the 15 copper strips, running them through the poles to the Trill board when necessary. When cutting wires for this part, allow enough length to get to the Trill, but not too long to clutter the internals. Solder the other ends of the wires **in order** from pico towards the end cap to pins 0-15 on the Trill board.

copper soldering | alternate view
--- | ---
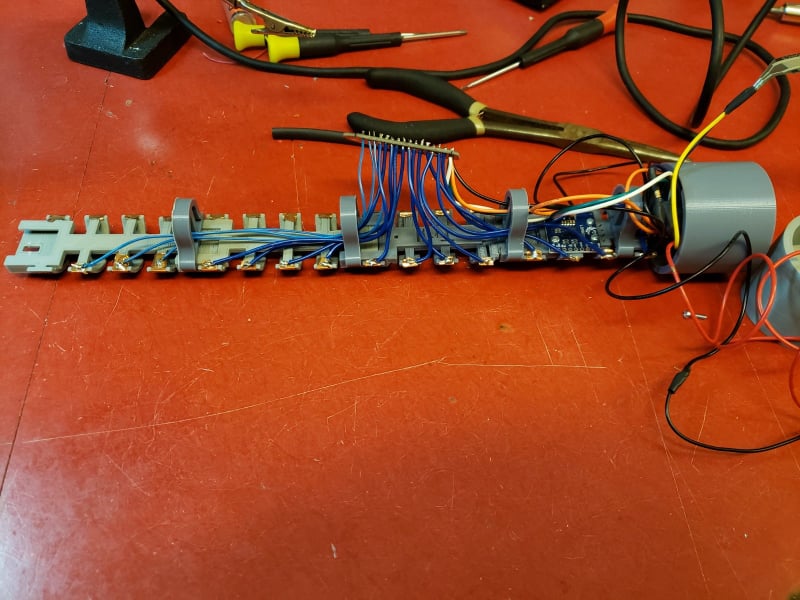
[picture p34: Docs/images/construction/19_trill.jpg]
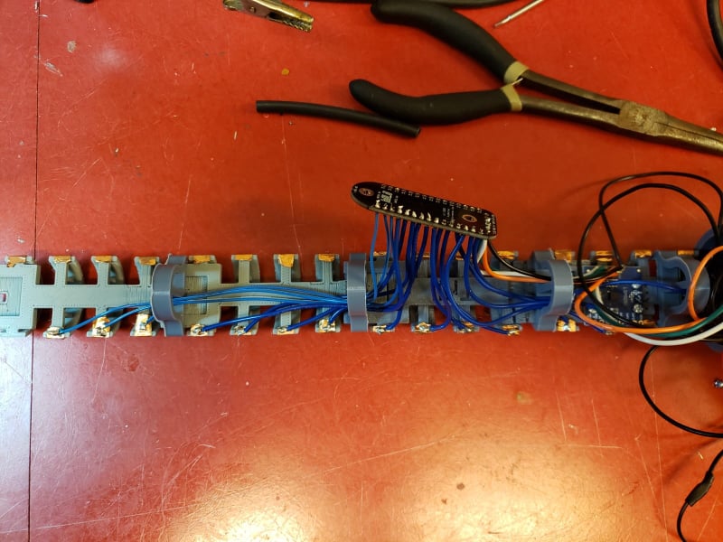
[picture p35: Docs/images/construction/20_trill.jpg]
 | 

Connect long wires from the 5V and GND pins of the TinyPICO (for the battery), and run them through the poles to the other end. Mount the IMU and Trill boards to their beds, and insert the TinyPICO into its slot in the end cap with the button. Slide the entire frame with the button cap into the PVC, making sure the long power wires can be accessed from the open end. Attach the FSR to the outside of the PVC, cutting the end if it's too long. Use the end cap's slot for the FSR wires to come out of the frame.

**IMU Mounting Note:**
Please install the IMU so that this configuration is kept consistent will the design.
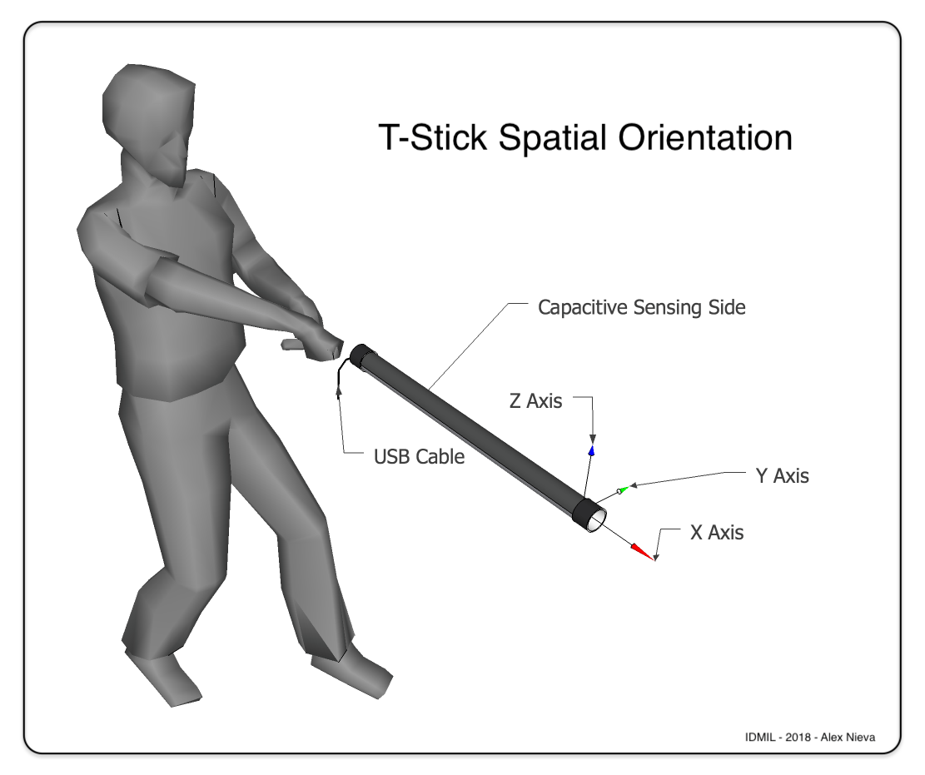
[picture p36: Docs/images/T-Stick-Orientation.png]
T-Stick Sopranino orientation


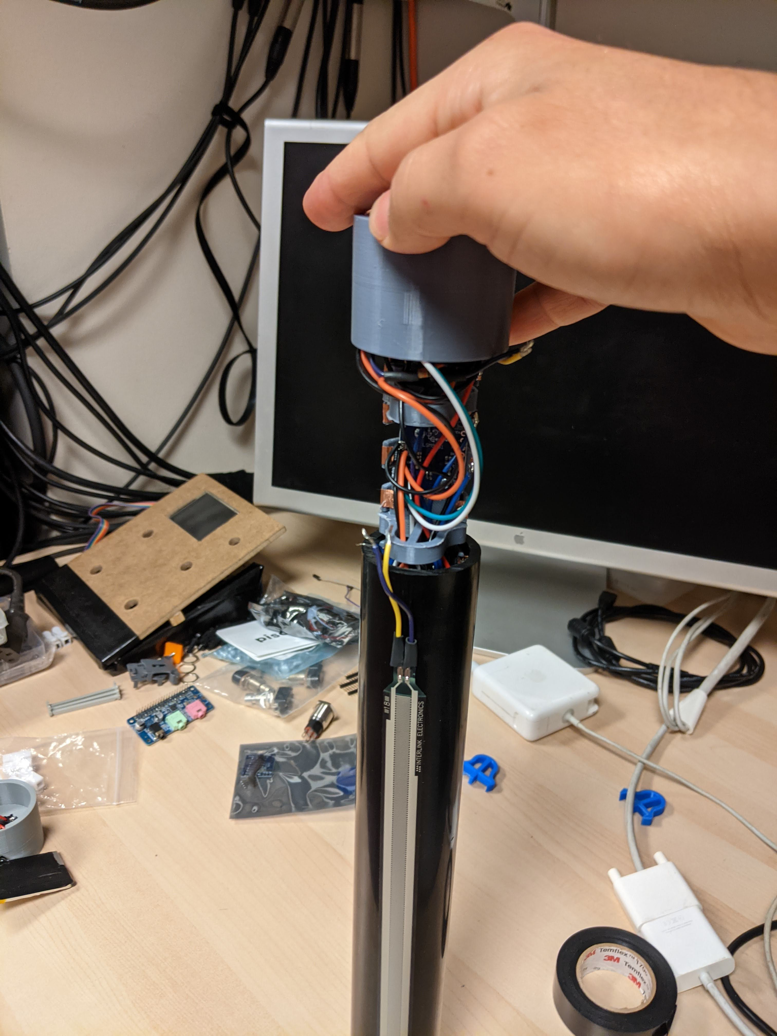
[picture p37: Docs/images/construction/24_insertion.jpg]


Insert the power switch into the other end cap. Solder the power wire of the battery to the power switch as in the picture below, twisting together the long power wire from the TinyPICO sticking out the end. Solder the long GND wire to the battery's GND.

**Important Note**: 2nd picture below should have ran the wires through the poles and inserted into the frame before soldering to the TinyPICO, be sure to do this before soldering the battery to the TinyPICO.

power soldering | power circuit view
--- | ---
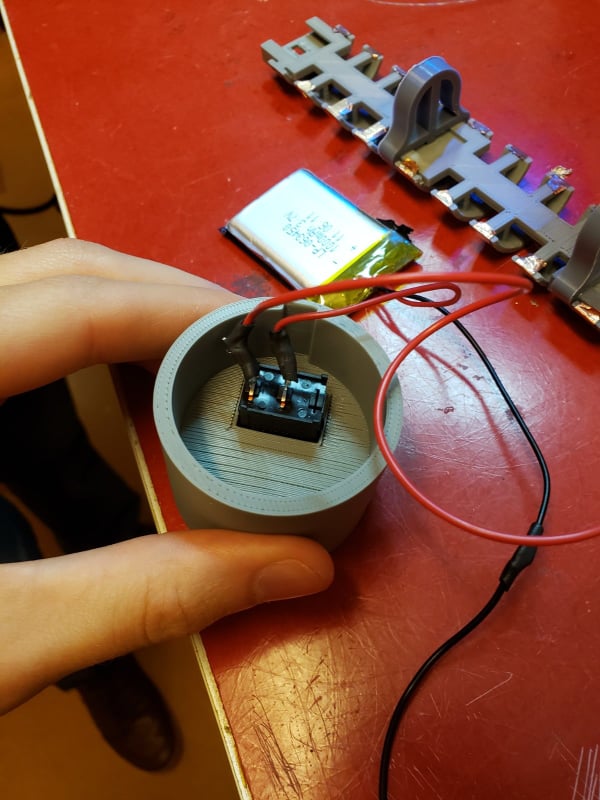
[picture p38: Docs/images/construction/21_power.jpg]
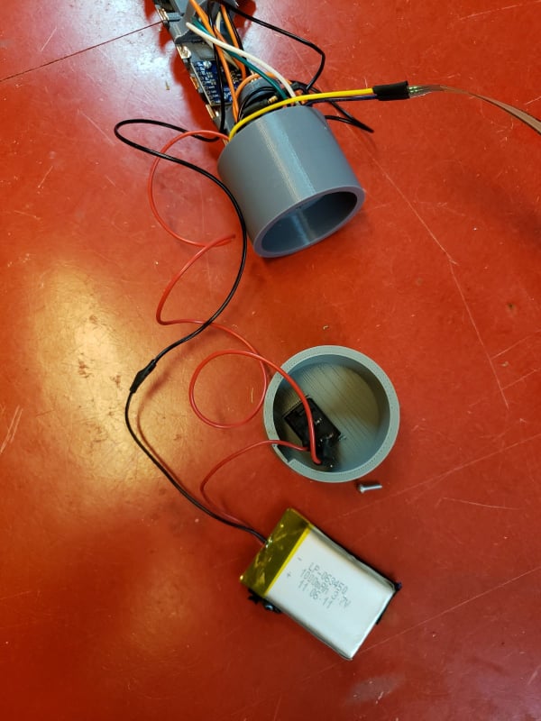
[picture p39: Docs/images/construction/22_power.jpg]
 | 

Hooray, you built a T-Stick!

### Firmware

Instructions to upload (flash) the T-Stick firmware and configuration files can be found [here](./Firmware_update_instructions.md).

Read and follow __ALL__ the instructions at before upload it to the board. There are some steps to prepare your machine and the ESP32 before flash it for the first time.

It is recommended to use the board test firmwares located [here](../Test_config) to test the sensors after install them.

## Document info

Version 1.2: Brady Boettcher
Version 1.1: Edu Meneses - eduardo.meneses@mail.mcgill.ca\
Version 1.0: Alex Nieva - alex.nieva@mail.mcgill.ca

__Input Devices and Music Interaction Laboratory__
http://www.idmil.org\
Schulich School of Music\
McGill University\
550 Rue Sherbrooke Ouest, Suite 500\
Montreal, QC, H3A 1E\
Canada

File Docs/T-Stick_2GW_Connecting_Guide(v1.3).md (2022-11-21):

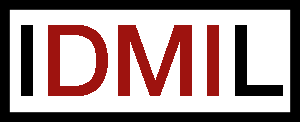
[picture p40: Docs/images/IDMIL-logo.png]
IDMIL logo
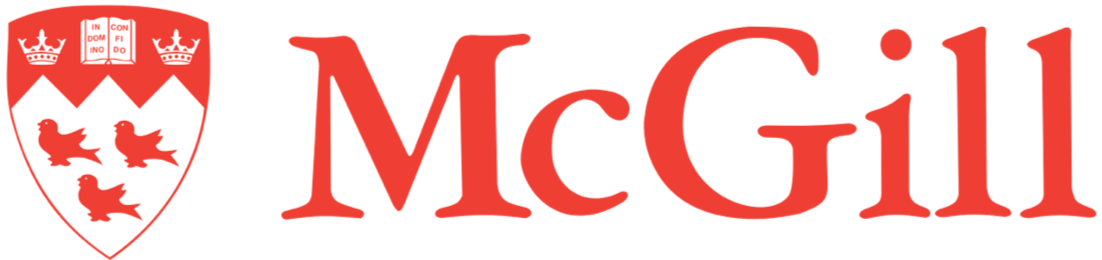
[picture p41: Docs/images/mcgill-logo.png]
McGill logo
 &emsp; &emsp; &emsp; &emsp; 

# T-Stick Connecting Guide (v1.3)

## Option 1: Wireless Connection
### Get your network details
1. Connect to the network you will be connecting the T-Stick to.
2. Note the SSID (network name) and SSID Password (network password).
3. Get your computers IP address while connected to this network. Below are linked some support articles for Windows, MacOS and Linux on how to find your computers IP address.
    - [Find your IP Address Windows](https://support.microsoft.com/en-us/windows/find-your-ip-address-in-windows-f21a9bbc-c582-55cd-35e0-73431160a1b9)
    - [Find your IP Address MacOS](https://discussions.apple.com/thread/253927735)
    - [Find your IP Address Linux](https://opensource.com/article/18/5/how-find-ip-address-linux)

### Connect to the T-Stick
4. Power on your T-Stick and wait until the boot sequence is complete. If your T-Stick does not have a Power switch press the button once and wait for the T-Stick to turn on.
5. Connect to the T-Stick_XXX wifi network where XXX is the ID of the T-Stick. ie: TStick_001. By default the password is mappings.
6. Open your browser and go to [http://TStick_XXX.local/](http://TStick_XXX.local/) or [http://192.168.4.1](http://192.168.4.1), where XXX is the ID of the T-Stick module.
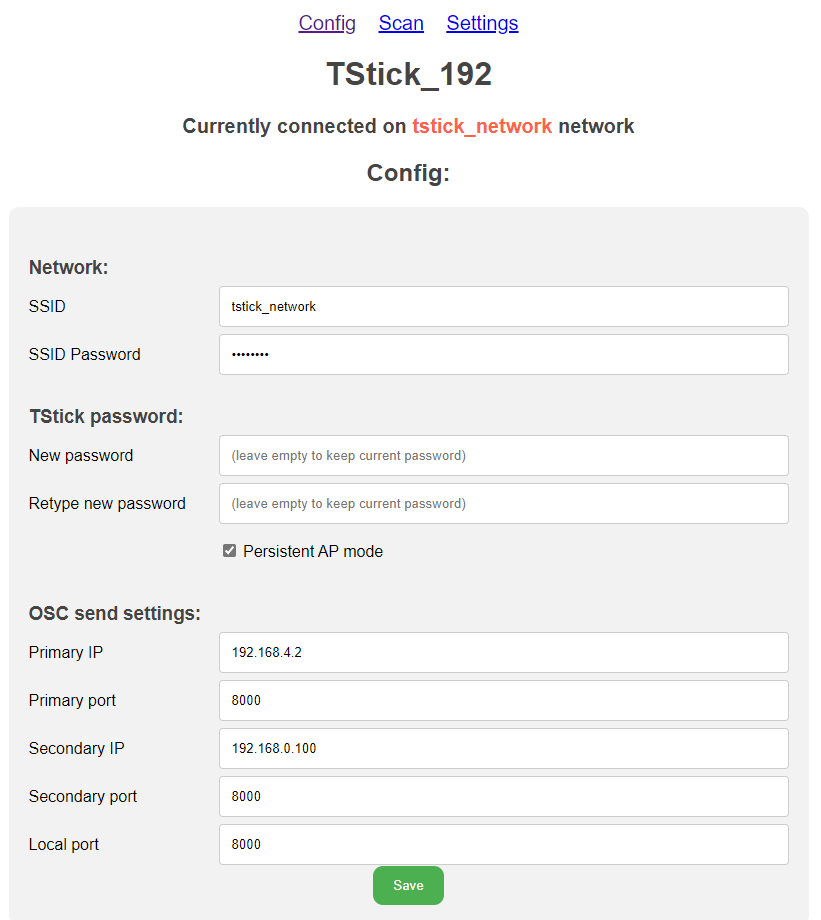
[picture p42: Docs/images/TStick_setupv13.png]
T-Stick setup page T-Stick wifi setup page

7. In the __Network__ section write the network name and password optained in Step 2 in the __SSID__ and __SSID Password__ fields. 
8. In the __OSC send settings__ put in your computer's IP address optained in Step 3 in the __Primary IP__ field.
8. Click the green __Save__ button. You will be directed to a page saying that the information was saved successfully.
6. Click __Config__ on the top of the page to return to the orginal menu.
7. Click the green __Close and Reboot__ button at the bottom of the page.

## Option 2: Puara Serial Manager
1. Download or clone the Puara client repository at https://github.com/Puara/puara-client. Instructions for how to clone github repositories can be found at the link below
    - [Cloning a Git Repository](https://docs.github.com/en/repositories/creating-and-managing-repositories/cloning-a-repository).
2. Open `config_template.json`.
3. Put in the network name you want the T-Stick to connect to in the __wifiSSID__ field.
4. Put the network password in the __wifiPSK__ field.
5. Save and close `config_template.json`.
6. Run the `puara_serial_manager.py` script.
7. Connect the T-Stick to your PC using a USB cable.
8. The script should auto detect and configure the T-Stick. If the T-Stick is not being detected you may need to download the CP210x USB driver. A link can be found on [Esspressif's website](https://docs.espressif.com/projects/esp-idf/en/latest/esp32/get-started/establish-serial-connection.html).

## Guide info:

Version 1.3: (2022/11/19) Albert-Ngabo Niyonsenga - albert-ngabo.niyonsenga@mail.mcgill.ca\
Version 1.2: (2020/03/20) Edu Meneses - eduardo.meneses@mail.mcgill.ca\
Version 1.11: (2019/11/27) Edu Meneses\
Version 1.1: (2019/10/27) Edu Meneses\
Version 1.0: (2019/08/28) Edu Meneses

__Input Devices and Music Interaction Laboratory__\
[http://www.idmil.org](http://www.idmil.org)\
Schulich School of Music\
McGill University\
550 Rue Sherbrooke Ouest, Suite 500\
Montreal, QC, H3A 1E\
Canada

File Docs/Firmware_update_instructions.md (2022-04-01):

# T-Stick 2GW (Firmware version: 220109)

- [T-Stick 2GW (Firmware version: 220109)](#t-stick-2gw-firmware-version-220109)
  - [First time firmware upload instructions](#first-time-firmware-upload-instructions)
    - [Option 1: using .bin files and esptool.py](#option-1-using-bin-files-and-esptoolpy)
      - [Download the bin files](#download-the-bin-files)
      - [Download esptool.py](#download-esptoolpy)
      - [Connect the T-Stick to the computer and check the USB port](#connect-the-t-stick-to-the-computer-and-check-the-usb-port)
      - [Flash the firmware (.bin files)](#flash-the-firmware-bin-files)
    - [Option 2: Using PlatformIO](#option-2-using-platformio)
      - [Install PlatformIO](#install-platformio)
      - [Clone the T-Stick repository](#clone-the-t-stick-repository)
      - [Open firmware project and flash it to the T-Stick](#open-firmware-project-and-flash-it-to-the-t-stick)
      - [Test T-Stick](#test-t-stick)
  - [Other Documentation](#other-documentation)
  - [Firmware information](#firmware-information)

## First time firmware upload instructions

### Option 1: using .bin files and esptool.py

This method is easier/faster. It uses [esptool.py](https://github.com/espressif/esptool).

#### Download the [bin files](../firmware/bin)

- Download the .bin files located at the [bin folder](../firmware/bin)

#### Download [esptool.py](https://github.com/espressif/esptool)

- Download the _esptool.py_ from [https://github.com/espressif/esptool](https://github.com/espressif/esptool). Use the `Download ZIP` option from Github
- Unzip the _esptool-master.zip_ file

#### Connect the T-Stick to the computer and check the USB port

- [Check the T-Stick (ESP32) port in your computer](https://docs.espressif.com/projects/esp-idf/en/latest/get-started/establish-serial-connection.html):
  - For MacOS/Linux:
    - install the [latest drivers from from the SiLabs website](https://www.silabs.com/developers/usb-to-uart-bridge-vcp-drivers).
    - Open a _Terminal_ window
    - Execute the command `ls /dev/cu.*`. The command will return a list of ports in your computer.
    - Plug the T-Stick (USB) and run the command `ls /dev/cu.*` one more time. You can now compare the lists and anotate the T-Stick USB port. Should be something similar to `/dev/cu.wchusbserial1410`, probably with a different number
    - Linux users should also give the currently logged user read and write access the serial port over USB. Check [here](https://docs.espressif.com/projects/esp-idf/en/latest/get-started/establish-serial-connection.html) for more information
  - For Windows:
    - Check the list of identified COM ports in the [Windows Device Manager](https://support.microsoft.com/en-ca/help/4026149/windows-open-device-manager)
    - Plug the T-Stick (USB) and check the list of identified COM ports in the [Windows Device Manager](https://support.microsoft.com/en-ca/help/4026149/windows-open-device-manager) again. The T-Stick port should appear on the list. Anotate the T-Stick USB port, it should be something similar to `COM3` or `COM16`

#### Flash the firmware (.bin files)

- Use _Finder_, _Terminal_, or _File Explorer_ to copy the contents of the [bin](../firmware/bin/) folder (you should copy 3 .bin files) to the _esptool-master_ folder
- Navigate to the _esptool-master_ folder in _Terminal_ or _Command Prompt_
- Run the command (__don't forget to replace the --port (/dev/cu.wchusbserial1410) option for your T-Stick port__): `esptool.py --chip esp32 --port /dev/cu.wchusbserial1410 --baud 115200 --before default_reset --after hard_reset write_flash -z --flash_mode dio --flash_freq 80m --flash_size detect 0xe000 boot_app0.bin 0x1000 bootloader_dio_80m.bin 0x10000 esp32_arduino_FW211124.bin 0x8000 esp32_arduino_FW211124.ino.partitions.bin 2686976 esp32_arduino_FW211124.spiffs.bin`. Wait for the process to be complete. Do not unplug or turn off your T-Stick during the process.

To set the T-Stick info and test if the data is being send correctly:

- Connect the T-Stick to a network (instructions [here](./T-Stick_2GW_Connecting_Guide(v1.2).md));
- Open the Pure Data (PD) or Max/MSP patch to receive T-Stick messages (they can be found [here](../Test_config/));
- Start receive OSC messages according to the chosen patch.

### Option 2: Using PlatformIO

_INSTALL ALL DEPENDENCIES AND REAL ALL OBSERVATIONS BEFORE UPLOAD !_

#### Install PlatformIO

To download and install PlatformIO, follow the instructions at [https://platformio.org/platformio-ide](https://platformio.org/platformio-ide).

We recomment using PlatformIO under Visual Studio Code, but you can also coose another editor.

#### Clone the T-Stick repository

Clone this repository using `git clone https://github.com/IDMIL/T-Stick.git`. Alternatively, you can download the repository as a zip file at [https://github.com/IDMIL/T-Stick](https://github.com/IDMIL/T-Stick). Take note of the folder location.

#### Open firmware project and flash it to the T-Stick

- Open the T-Stick firmware project (folder **firmware** in the T-Stick repository folder) in VSC/PlatformIO. You can get help on how to use PlatformIO at [https://docs.platformio.org/en/latest/core/quickstart.html](https://docs.platformio.org/en/latest/core/quickstart.html)
- You can make any necessary changes on the firmware before flashing (e.g., changing T-Stick ID, selecting the board and capacitive board accordingly)
- If it is the first time flashing, you may see an error pointing to the ESP32 inet.h file. The file requires manual fixing. Check the issue at [https://github.com/mathiasbredholt/libmapper-arduino/issues/3](https://github.com/mathiasbredholt/libmapper-arduino/issues/3)

When ready, you need to flash both the firmware and the filesystem image. Choose the proper platform accordingly (*lolin_d32_pro* or *tinypico*) and use the PlatformIO menu to flash both images to the T-Stick.

#### Test T-Stick

After flashing, you can use the VSC/PlatformIO serial monitor to check if the T-Stick is booting properly. You should see T-Stick booting process.

You can also interact with the controller using the following commands:

- 's' to start setup mode
- 'r' to reboot
- 'd' to enter deep sleep

To test if the data is being send correctly:

- Connect the T-Stick to a network (instructions [here](./Docs/T-Stick_2GW_Connecting_Guide(v1.2).md))
- Open the Pure Data (PD) or Max/MSP patch to receive T-Stick messages (they can be found [here](./Configuration))
- Start receive OSC messages according to the chosen patch

## Other Documentation

[T-Stick connection guide – v1.2 for wireless T-Sticks](./T-Stick_2GW_Connecting_Guide(v1.2).md)

[How to build a T-Stick Sopranino](./T-Stick_2GW_building_instructions.md)

## Firmware information

Sopranino T-Stick 3G - LOLIN D32 PRO / TinyPico - USB - WiFi
Input Devices and Music Interaction Laboratory (IDMIL)

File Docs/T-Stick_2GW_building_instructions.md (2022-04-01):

# Building a Sopranino T-Stick (v1.2)

## Bill of Materials:

Qty   | Description
------|---------------------
01    | [Trill](https://shop.bela.io/products/trill-craft/)     
01    | [TinyPICO](https://www.adafruit.com/product/4335)        
01    | [IMU breakout board LSM9DS](https://www.sparkfun.com/products/13284)
01    | [FSR 408](https://www.robotshop.com/ca/en/interlink-24-long-fsr.html)
01    | 1K resistor
01    | [10K potentiometer](https://www.digikey.com/products/en?mpart=PV36W103C01B00&v=118)
01    | [button](https://www.digikey.ca/product-detail/en/c-k/PTS125SM43-2-LFS/CKN9100-ND/1146743)
01    | Li-Po Battery min 1000mA
01    | PVC Tube (30 cm)
~85cm | Copper adhesive tape
01    | [ON-OFF rocker switch](https://www.digikey.ca/product-detail/en/RA1113112R/EG5619-ND/3778055/?itemSeq=307636370)
~35cm | Heat shrink tube
01    | end-cup with microcontroller base
01    | end-cup with for the ON-OFF switch
01    | [3D printed bases](../3D_printing/), one of each file, and 4 regular poles
11    | [M2 Mounting Screws](https://www.digikey.ca/product-detail/en/MPMS+002+0008+PH/H739-ND/274950/?itemSeq=307635387)
01    | [foam sheet](https://www.amazon.ca/Craft-Foam-Sheets-Assorted-Colours/dp/B005EQPRM6)

## Instructions:

#### Printing the Frame:

Print one of each of the [3d printing files](../3D_printing/), but print 4 copies of the "regular poles".
The beds (pieces that snap together) will need supports on the piece that snaps.

Overview 3d printing overview

Snap the beds together as in the image above, snapping the regular poles between beds to secure them.
Place copper strips on each arc in the beds, these will be used for capacitive touch sensing.

#### Soldering Components

All the building tools can be found in the Machine Shop at the McGill Music Tech Department.

Overview_wires wiring overview

Let's start with the end cap where the TinyPICO will be inserted. Insert the button into the slot like the pictures below. Note that it is possible to solder all future three wires to the button before inserting it in the slot, in order to make the soldering more accessible.

button top view| button bottom view | soldering
--- | --- | ---
 |  | 

Solder 2 wires diagonally to the button pins, connecting one to GND and one to pin 15 on the TinyPICO. For the GND connection, twist an extra wire together before soldering to the TinyPICO, which will be used for connecting the IMU later on.

connecting to TinyPICO | completed button circuit
--- | ---
 | 

To prepare the resistor for its FSR connection, solder 2 wires to one end and 1 to the other like below. Use heat shrink to wrap the connection. Solder the single end wire to a GND pin on the button (shared pins on the provided button are opposite of each other, in doubt check the specifications in the bill of materials). Solder one of the double end wires to pin 33 on the TinyPICO. 

soldering | heat shrinking | connecting to TinyPICO
--- | --- | ---
 |  | 

Prepare the FSR connections by carefully soldering 2 wires to its terminals, using the extra wire form the resistor as one of the terminals. Be cautious not to melt the plastic on the FSR if possible by soldering quickly. Heat shrink the terminals when complete. 

soldering | heat shrinking
--- | ---
 | 

Solder the other FSR wire **and** another wire (which will connect to the IMU) to the 3V3 pin on the TinyPICO (yellow and orange in the picture below). Twisting the 2 wires together before inserting into the pin will make this task easier.

twisting and soldering | view of 3V3 pin
--- | ---
 | 

Solder 2 wires to each of the IMU's GND, VCC, SDA and SCL pins. One of the VCC wires and one of the GND wires should be the extra 3V3 and GND wires from the TinyPICO that you put in in the above steps. Connect one of the SDA wires to pin 21 of the TinyPICO, and one of the SCL wires to pin 22 of the TinyPICO. 

twisting and soldering | connecting to TinyPICO | imu wiring
--- | --- | ---
 |  | 

At this stage, the IMU should have unconnected wires (1 of each) from SDA, SCL, GND and VCC. Run the 4 unconnected wires through the pole and solder to the corresponding labeled pins on the Trill (with the VCC pin of the IMU connected to the +V pin of the Trill).

trill connections | alternate view
--- | ---
 | 

Now for the fun part ;). Solder wires onto each of the 15 copper strips, running them through the poles to the Trill board when necessary. When cutting wires for this part, allow enough length to get to the Trill, but not too long to clutter the internals. Solder the other ends of the wires **in order** from pico towards the end cap to pins 0-14 on the Trill board. On the Sopranino design, leave the strip at the extremity on the side of the TinyPICO unconnected, and connect the 15 other strips.

copper soldering | alternate view
--- | ---
 | 

Connect long wires from the 5V and GND pins of the TinyPICO (for the battery), and run them through the poles to the other end. Mount the IMU and Trill boards to their beds, and insert the TinyPICO into its slot in the end cap with the button. Slide the entire frame with the button cap into the PVC, making sure the long power wires can be accessed from the open end. Attach the FSR to the outside of the PVC, cutting the end if it's too long. Use the end cap's slot for the FSR wires to come out of the frame.

**Important Note:** In the design with the removable 3.7V battery, the switch is not present and the T-Stick will be powered on and off with the button. The battery container should be linked to the GND and Bat pins of the TinyPICO. The battery slot will be placed on the opposite end of the TinyPICO and should be pullable out of the opening of the cap for battery replacement.

**IMU Mounting Note:**
Please install the IMU so that this configuration is kept consistent with the design.
T-Stick Sopranino orientation



Insert the power switch into the other end cap. Solder the power wire of the battery to the power switch as in the picture below, twisting together the long power wire from the TinyPICO sticking out the end. Solder the long GND wire to the battery's GND.

**Important Note**: 2nd picture below should have ran the wires through the poles and inserted into the frame before soldering to the TinyPICO, be sure to do this before soldering the battery to the TinyPICO.

power soldering | power circuit view
--- | ---
 | 

Hooray, you built a T-Stick!

#### Firmware:

Instructions to upload (flash) the T-Stick firmware and configuration files can be found [here](../README.md).

Read and follow __ALL__ the instructions at before upload it to the board. There are some steps to prepare your machine and the ESP32 before flash it for the first time.

It is recommended to use the board test firmwares located at https://github.com/IDMIL/TStick/tree/master/Sopranino/2GW/19X/Tests to test the capsense board and the IMU after install them.

Nightly builds and beta firmwares can be downloaded at https://github.com/edumeneses/TStick. Before using them, contact the IDMIL's lab team.

## More info:

Version 1.2: Brady Boettcher
Version 1.1: Edu Meneses - eduardo.meneses@mail.mcgill.ca\
Version 1.0: Created by: Alex Nieva - alex.nieva@mail.mcgill.ca

__Input Devices and Music Interaction Laboratory__
http://www.idmil.org\
Schulich School of Music\
McGill University\
550 Rue Sherbrooke Ouest, Suite 500\
Montreal, QC, H3A 1E\
Canada

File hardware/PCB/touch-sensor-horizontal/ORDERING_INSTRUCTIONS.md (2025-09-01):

# How to order touch sensor from JLCPCB and PCBWAY

This file contains instructions for ordering the touch-sensor from JLCPCB or PCBWAY. Both companies offer relatively cheap Flexible PCB options however JLCPCB is significantly cheaper for small runs.

## Ordering from JLCPCB
1. Click the blue **Instant Quote** button.
2. Select **Flex** as the Base material.
3. Click the blue **Add gerber file** button.
4. Select the **touch-sensor-horizontal.kicad_pcb.zip** from this folder and upload it. Several options should now be automatically filled out such as the layers and dimensions.
5. Select the appropriate PCB Qty.
6. Under **PCB Specifications** change _PCB Thickness_ to 0.2.
7. Under **High-spec Options** change the following settings:
    - _Gold Fingers_ = Yes
    - _Gold Fingers Thickness_ = 0.3mm
    - _Stiffener_ = Polymide + 3M Tape
    - _Polymide Thickness_ = 0.1mm
    - _3M Tape Thickness_ = 3M468
8. Click the blue _Save to Cart_ option and follow the prompts to pay for the PCB. You may choose to wait until review to pay but note that production will be delayed until payment. 
9. Make sure to check your inbox 24-72 hours after the purchase as JLCPCB might contact you regarding any questions about the order.

## Ordering from PCBWAY
1. Click the **PCB Instant Quote** button in the taskbar at the top of the screen.
2. Select **FPC/Rigid-Flex** PCB.
3. Change the following settings:
    - _Layers_ = 2
    - _Quantity_ = set as desired (note that small orders are really expensive)
    - _FPC Thickness_ = 0.2
    - _Edge Connector_ = Yes
    - _TOP PI_ = 0.1mm
    - _3M/Tesa Tape_ = 3M467, onesided BOT
    - _E-test_ = No (optional, to reduce cost)
4. Click save to cart.
5. In the next screen click the green **Add Gerber File** button. 
6. Select the **touch-sensor-horizontal.kicad_pcb.zip** from this folder and upload it. 
7. Make sure to check your inbox 24-72 hours after the purchase for PCBWAY to review the file and give the final quote.
8. Once the paid the order will go into production.

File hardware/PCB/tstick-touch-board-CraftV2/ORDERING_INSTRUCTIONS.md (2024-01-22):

# How to order board from PCBWAY

This file contains instructions for ordering the a PCB from PCBWAY for both fabrication and assembly. If you have the PCBWAY plugin from Kicad you can press use the plugin and skip straight to step 10

## Ordering from PCBWAY
1. Click the **PCB Instant Quote** button in the taskbar at the top of the screen.
2. Click the green **Quick-order PCB>>** button.
3. Press the grey **+Add Gerber File** button.
4. Select the **.kicad_pcb.zip** file. Several paramaeters should now autofill.
    - For a 4 layer board it may ask you to specify the layer names and order you should fill in the following:
        - L1 = F.Cu
        - L2 = In1.Cu
        - L3 = In2.Cu
        - L4 = B.Cu
5. Select the appropiate quantity.
6. Scroll further down to the **Assembly Service** section and click it.
7. Write the appropriate quantity of boards you wish to be assembled.
8. Click the green **Save to Cart** button.
9. You will now see two orders one for the fabrication and the other for assembly. Click the blue **Add files button for assembly**.
10. Click the **Parts List (BOM) Upload** and add the **BOM.csv** file for the board. 
    - Note that if you used the Kicad plugin you will need to remove the BOM file that has been uploaded as it does not have all the information needed.
11. _(Optional)_ Click the **Upload Centroid File** button and add the **PCBWay_positions.csv** file. This file is already in the **.kicad_pcb.zip** file but the customer support may require you to submit it seperately.
12. Make sure to check your inbox 24-72 hours after the purchase for PCBWAY to review the file and give the final quote.
13. Once the paid the order will go into production.

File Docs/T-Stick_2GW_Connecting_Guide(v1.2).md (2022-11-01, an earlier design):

IDMIL logo &emsp; &emsp; &emsp; &emsp; McGill logo

# T-Stick Connecting Guide (v1.2)

This guide will show how to connect the T-Stick to a computer running macOS. This guide was tested on macOS Mojave, but it should work on older versions. To connect on Windows or Linux machines the procedure is similar, and this guide can serve as well.

Once this process is done, the T-Stick should connect to the computer automatically as long as both the computer and the T-Stick maintain the same IP address and use the same network.

The process, after learned, should take no more than 3min.

## 1-) Enter T-Stick setup, and connect to a network:

- Turn the T-Stick on:

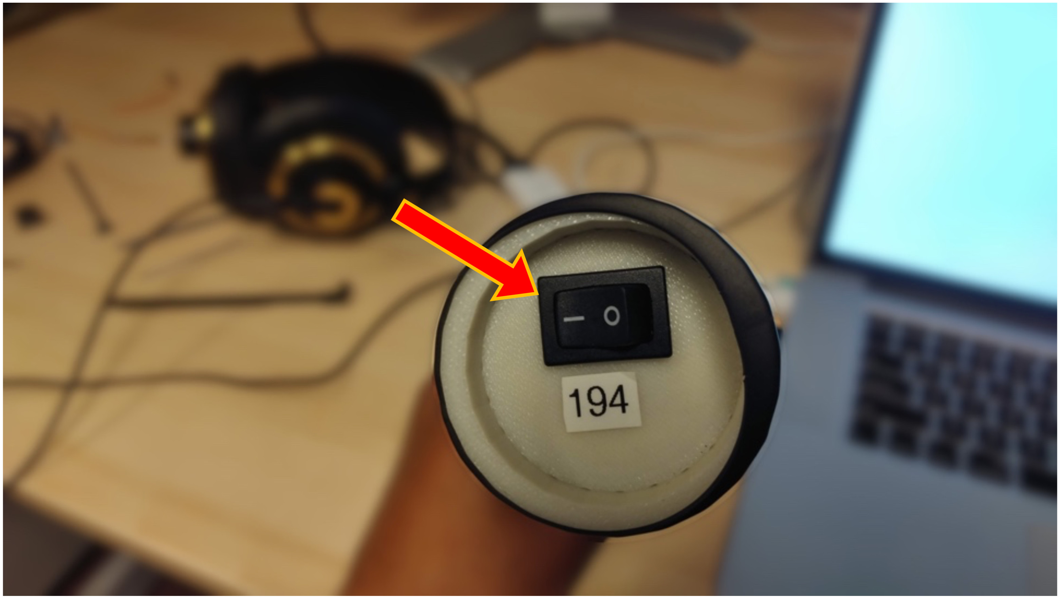
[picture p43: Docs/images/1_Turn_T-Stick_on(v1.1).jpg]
Turn the T-Stick on


- Push the setup button for at least 3 seconds (long press) to enter AP-mode. The T-Stick will then create an access point.

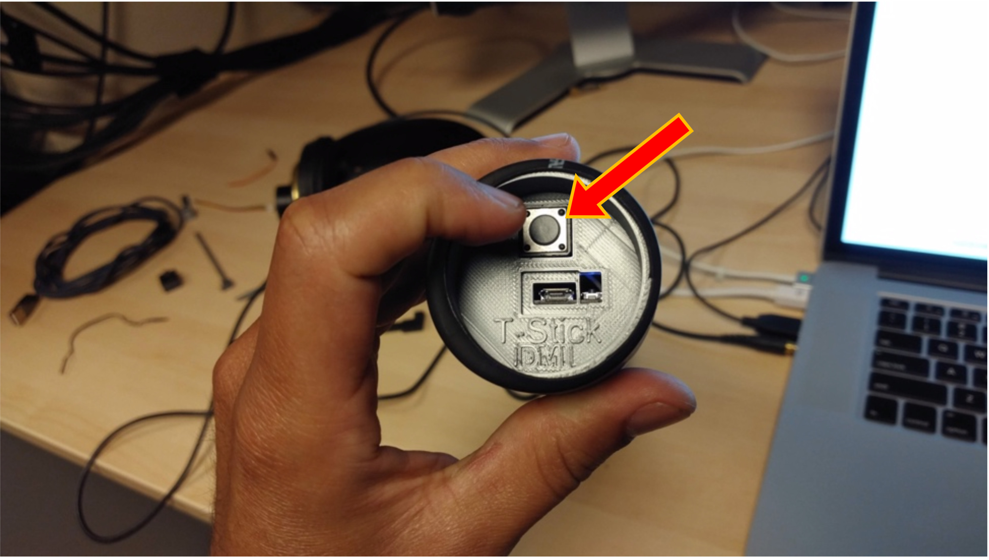
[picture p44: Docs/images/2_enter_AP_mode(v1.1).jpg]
Enter AP mode


-  Connect to the T-Stick network (default password: `mappings`):

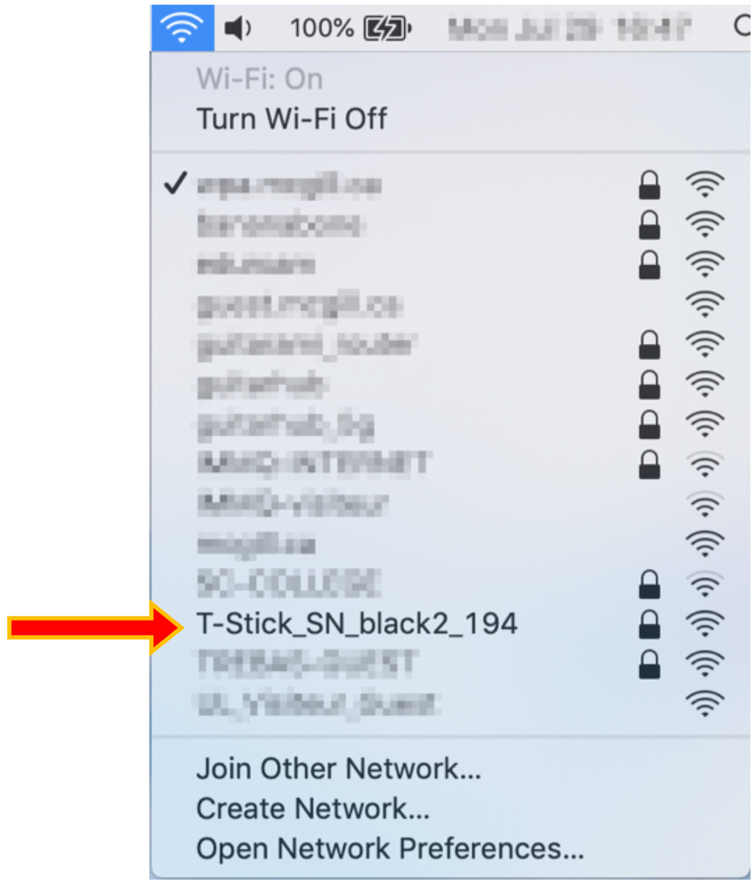
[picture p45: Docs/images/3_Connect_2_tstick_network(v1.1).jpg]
Connect to the T-Stick network


- The setup portal should open automatically as soon as the computer connects to the T-Stick network. In case the setup portal does not open, locate the T-Stick's IP address (e.g. run `arp -a` or `ip route` at the command line on linux), and navigate to that address with your web browser.
- The page will inform the saved SSID and connection status. Click on Configuration.

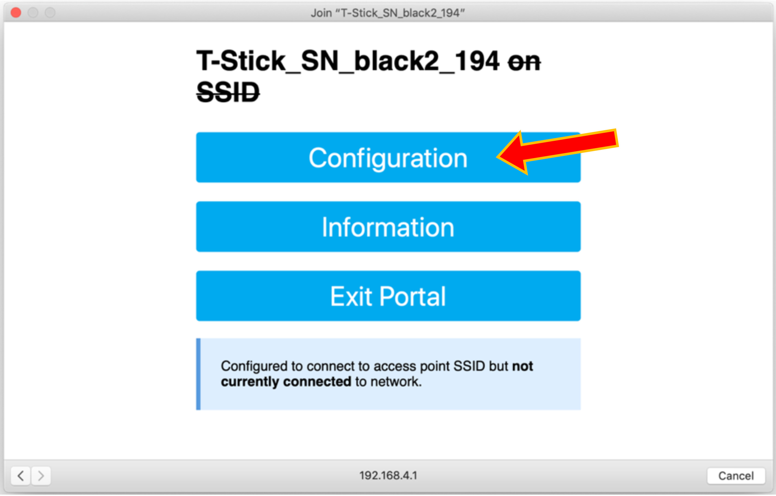
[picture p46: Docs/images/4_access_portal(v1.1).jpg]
Access portal


- Choose the Wi-Fi network that will be used to connect the T-Stick and the computer. In this guide, we will use the _guitarami\_router_ network. Don’t forget to type the password (be
careful, the password is never hidden).

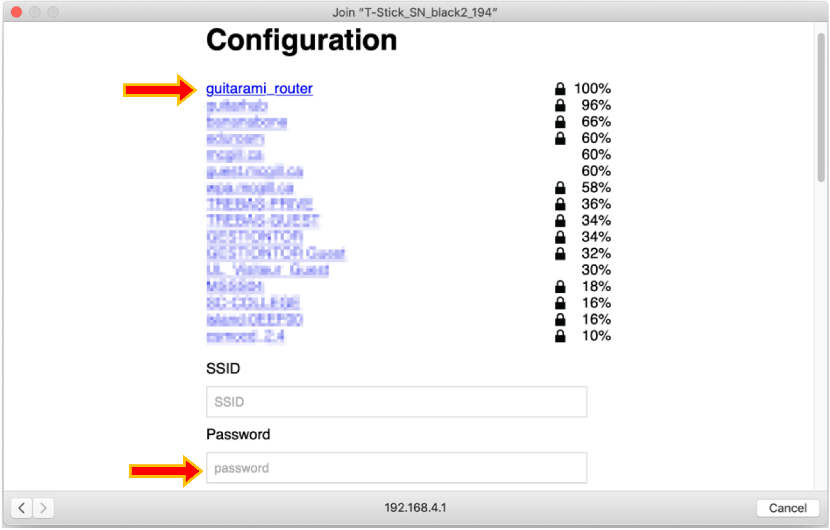
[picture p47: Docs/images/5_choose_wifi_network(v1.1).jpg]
Choose wifi network


- Go to the end of the page and save your settings.

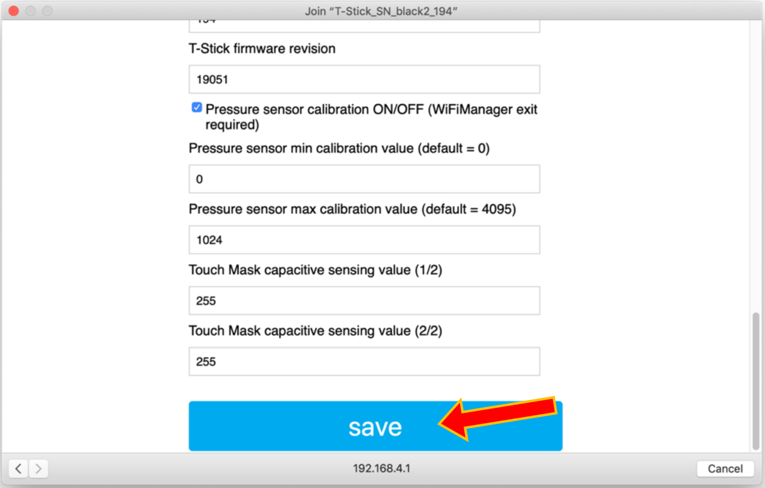
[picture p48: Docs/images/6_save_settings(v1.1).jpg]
Save settings


- Wait at least 5 seconds before click in __how it went__. This will take you to the main setup page.
- If your configuration page differs from that shown, you may need to return to the config page, scroll to the bottom, and reboot your T-Stick, at which point it should connect to the configured network (_guitarami/_router_ in our example).

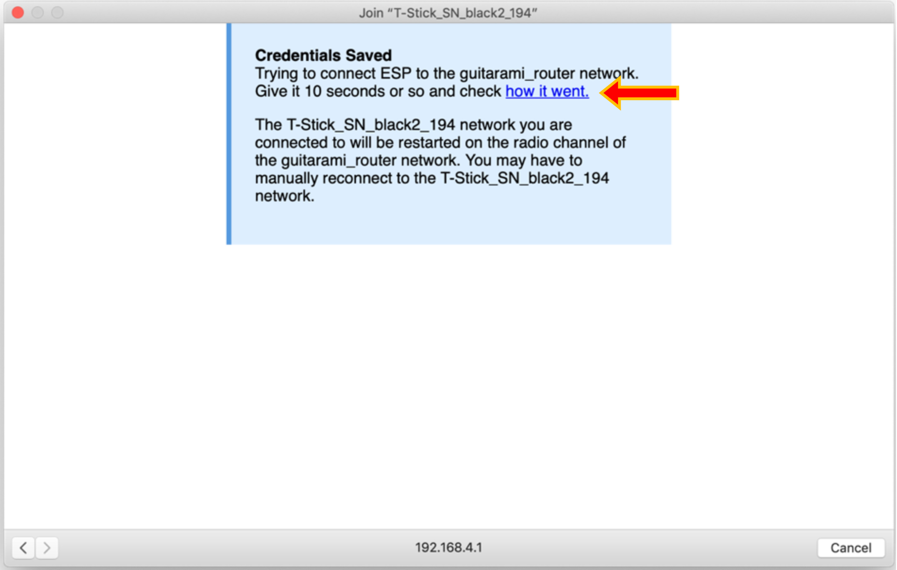
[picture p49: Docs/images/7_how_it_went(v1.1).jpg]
How it went


- Check if the T-Stick is connected and if an IP was attributed to the instrument. Take note of the T-Stick IP address. Leave the portal open (do not hit __exit portal__).

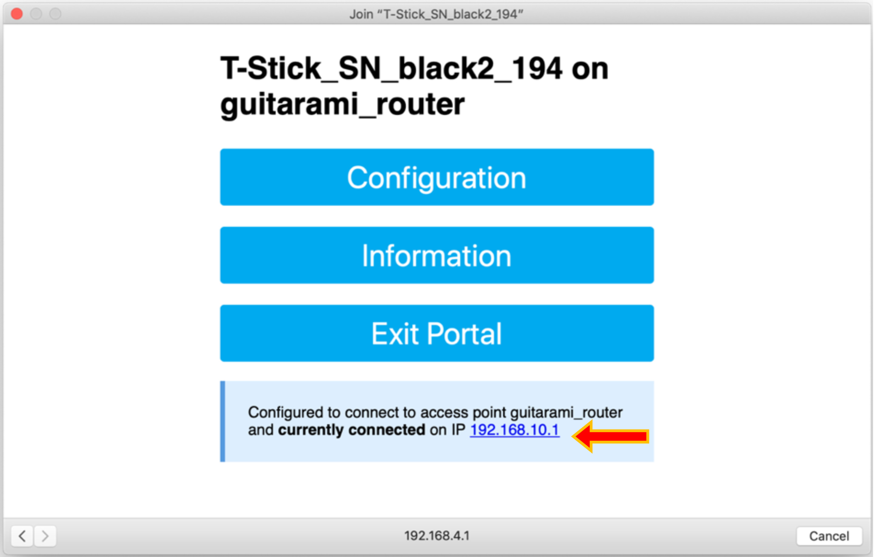
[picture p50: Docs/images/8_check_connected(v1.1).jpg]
Check if connected


## 2-) Connect your computer/device to the same network, and access the T-Stick setup though the browser:

- Connect your computer to the same network the T-Stick currently is. In your case, we will connect to _guitarami\_router_.

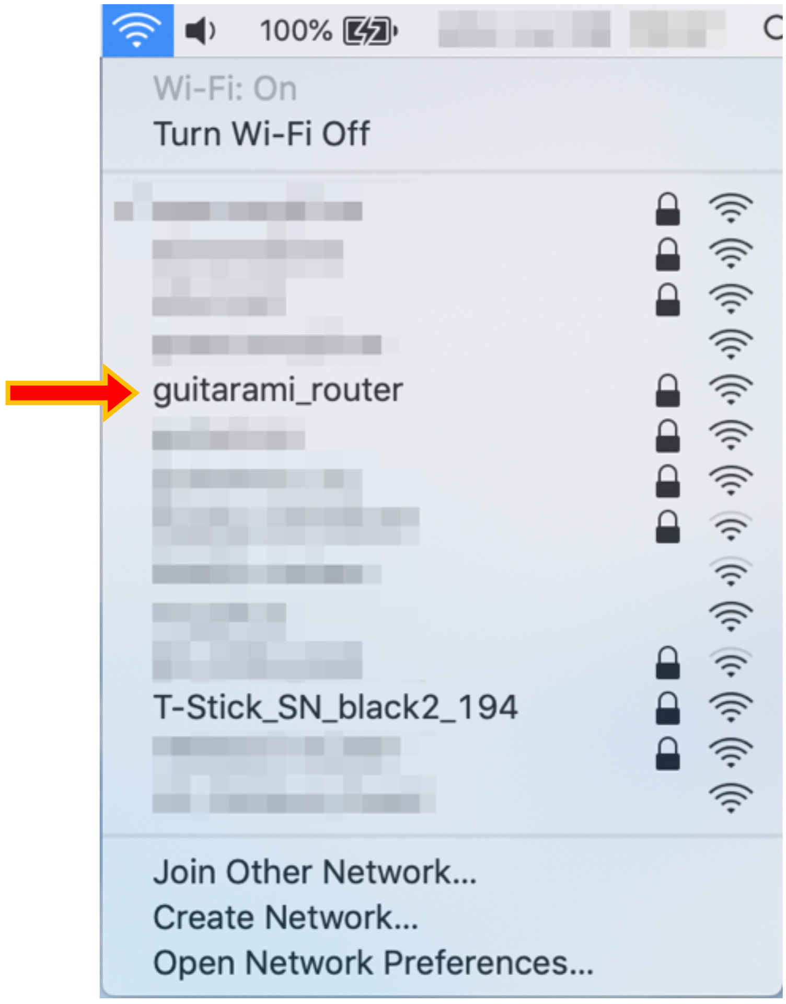
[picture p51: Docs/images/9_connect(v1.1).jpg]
Connect


- Open your web browser and type the T-Stick IP address to access the setup portal using the chosen network.

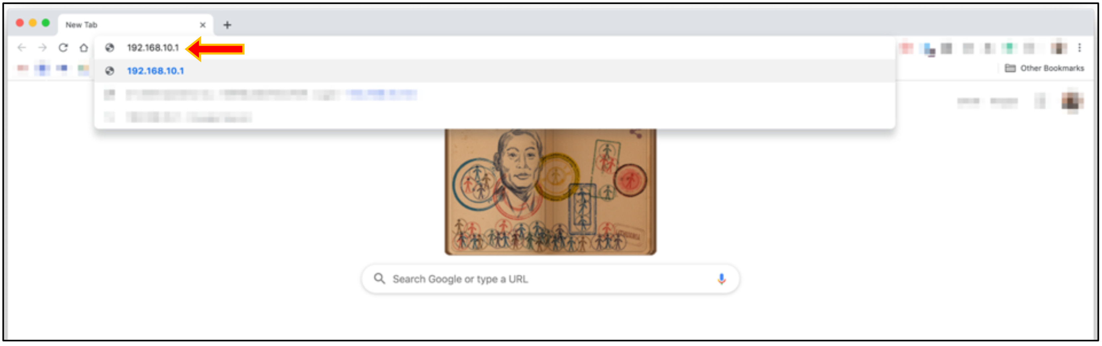
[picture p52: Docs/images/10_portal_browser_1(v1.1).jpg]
Portal browser (1)


You will see the main portal screen through the web browser. Enter “Configuration” one more time.

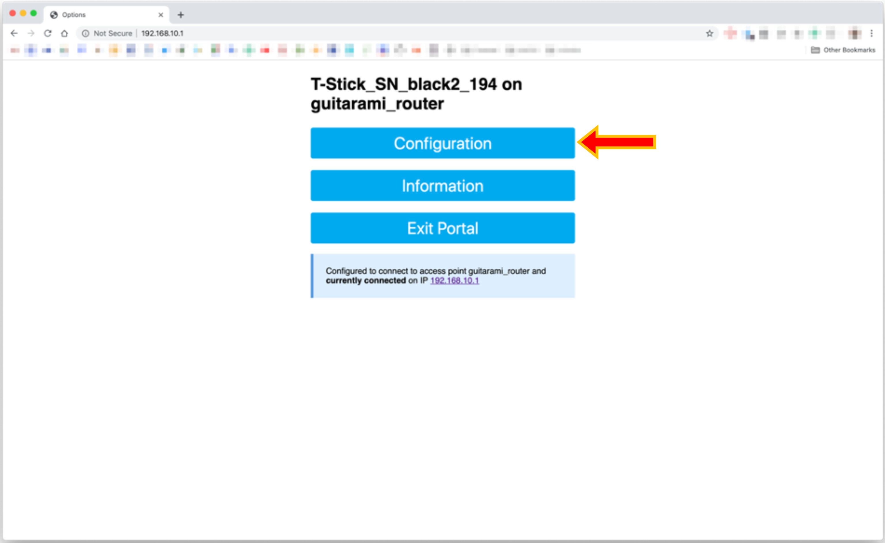
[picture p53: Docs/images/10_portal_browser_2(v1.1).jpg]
Portal browser (2)


## 3-) Configure IP address/port to send OSC messages:

- Check the computer’s current IP (in macOS, you can hold the _Option_ key and hit the Wi-Fi icon to check that information). Copy the computer’s IP into the field “IP to send OSC messages”. Hit “Save”.

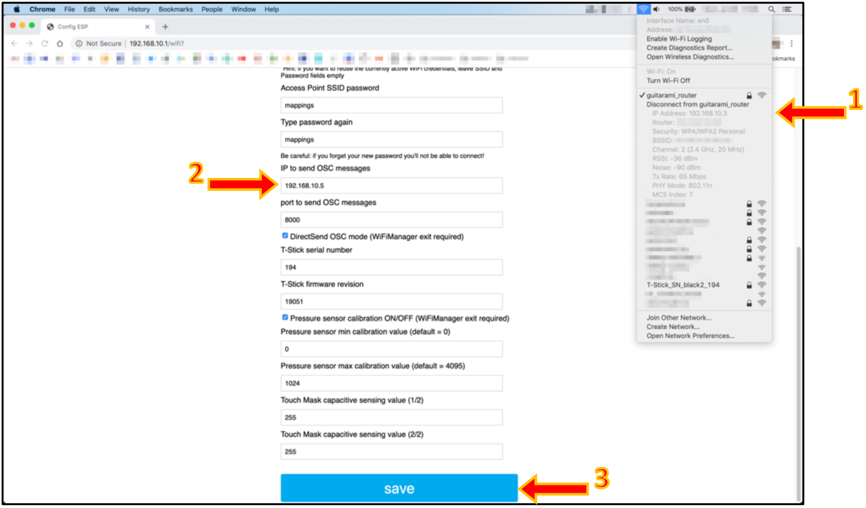
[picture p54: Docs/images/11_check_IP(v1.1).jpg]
Check computer's IP


- Wait 5 more seconds and hit __how it went__:

How it went again

- Check if the T-Stick is connected and hit __Exit Portal__. The T-Stick will start send information after the portal closes.

Exit portal

- You can now close your browser and play the T-Stick.

Close browser

## Guide info:

Version 1.2: (2020/03/20) Edu Meneses - eduardo.meneses@mail.mcgill.ca
Version 1.11: (2019/11/27) Edu Meneses
Version 1.1: (2019/10/27) Edu Meneses
Version 1.0: (2019/08/28) Edu Meneses

__Input Devices and Music Interaction Laboratory__\
[http://www.idmil.org](http://www.idmil.org)\
Schulich School of Music\
McGill University\
550 Rue Sherbrooke Ouest, Suite 500\
Montreal, QC, H3A 1E\
Canada

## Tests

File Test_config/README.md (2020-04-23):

# T-Stick Module Tests and Capsense configuration

Contains both arduino sketches (may need to check library dependencies) and compiled binaries that can be uploaded directly using the [ESP flash download tool](https://www.espressif.com/en/support/download/other-tools) (Windows only), or the python script [esptool](https://github.com/espressif/esptool).

We recommend using the Arduino UNO to test the boards, since some ESP32 boards doesn't have proper protection for the I2C bus.

## Compiling from scratch

Alternatively, you can compile these examples in the Arduino IDE with the following libraries:

- Adafruit LSM9DS1
- Adafruit Sensor

Also, make sure you have the esp32 build system installed with the Arduino IDE!

# MAKE SURE YOU CONNECT THE SENSOR BOARDS IN THE RIGHT ORIENTATION!!!

## full_I2C_test:
- LSM9DS1 test using Adafruit library. Spits out IMU data through serial port after initialization
- Tests the Capsense board by itself. It should work with just the ESP32 board + multiple IDMIL's Capsense boards. Once the sketch is running, you should be able to rub your fingers on the pin pads where the copper strips will be connected to, and see the finger touch detected through packed bytes sent via the serial port.

## Capsense_config:
- Perform the IDMIL's capsense test, but also allows configuring the board. Use this sketch to set the I2C address to connect multiple capsense boards.

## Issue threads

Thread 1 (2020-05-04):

Eagle Schematic does not include config button

jrohs, 2020-05-04:
There is no reference to where the configuration button should be connected in the documentation or on the schematic. (Latest Firmware says Pin 15) but this should be shown in the schematic diagram and/or referenced in documentation.

edumeneses, 2021-01-24:
Definitely, also, we simplified the FSR connection, and I'm advocating to remove the piezo.

We'll have to redo the schematic to reflect all these changes.

edumeneses, 2021-11-24:
Still open as we need to redo the schematics

Closed 2025-09-01.

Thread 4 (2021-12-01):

TinyPico LED not working

edumeneses, 2021-12-01:
FW211124 code for the TinyPico LED isn't working. Probably some typo or wrong implementation.

Closed 2022-04-04.

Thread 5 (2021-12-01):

18650 battery not charging on the 3G T-Sticks

edumeneses, 2021-12-01:
TinyPicos can charge the Lipo batteries, but not the 18650. In a conversation with the folks from Unexpected Maker, it may be something related to chemistry (the 18650 shouldn't be able to charge all the way up anyway).

It can also be that the batteries purchases at IDMIL are not great. We need to run some tests and see how to fix it. In the meantime, we need to charge them outside the T-Stick.

edumeneses, 2021-12-14:
This was caused by a firmware problem that is now solved. We need to confirm it is charging and close the issue.

Closed 2022-04-04.

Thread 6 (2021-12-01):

Libmapper crashes on FW211124

edumeneses, 2021-12-01:
Libmapper crashes when creating signals during boot time. This is not a libmapper issue (the libmapper-Arduino example works fine).

mathiasbredholt, 2021-12-01:
Hi @edumeneses, are you creating signals after connecting to wifi?

edumeneses, 2021-12-01:
Yes, I checked that. I'm installing ArduinoIDE again as I had a flatpack before and couldn't decode the exception. I'll check it soon

edumeneses, 2021-12-07:
I fixed this issue. I'll keep this open until someone tests it.

Closed 2021-12-14.

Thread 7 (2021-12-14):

exact yaw data not detected

takujin3, 2021-12-14:
What we need to do is put Joe's code and take Travis' library out of the firmware.
It also needs some configuring and testing to see if it works.

DocSunset, 2022-01-03:
Just curious where I may review Joe's code to compare with my own. There may be simpler solutions than throwing out my sensor fusion and calibration code.

malloch, 2022-01-03:
@DocSunset https://github.com/malloch/Arduino_IMU (on GitHub since 2013)

malloch, 2022-01-03:
Looking at the firmware in this repo, the magnetometer gain `k_m ` is initialized to zero (IMU.ino line 13) so no big surprise that azimuth is not calculated properly!

DocSunset, 2022-01-03:
Thank @malloch. I believe the magnetometer is initially turned off because the sensors we were using last time I looked at this firmware were worse than useless unless calibrated beforehand (e.g. causing severe yaw drift due to sensor bias). [My python scripts for calibrating the sensor](https://github.com/DocSunset/pyMIMU/tree/wiporganize/pyMIMU) have some severe usability shortcomings though, and are possibly just generally broken as I last left them in the middle of some extensive refactoring... if/when I get a T-Stick running in France I plan to revisit them and get things working properly.

takujin3, 2022-06-07:
Hello @malloch @DocSunset ! Let me know whenever you made some improvements on this issue. It would be great if the problem could be solved by the end of September or so since I am wondering to use the yaw data during the workshop planned for Fall 2022 and/or Winter 2023. Thanks for your work!

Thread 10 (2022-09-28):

Signal range corrections

bboettcher3, 2022-09-28:

edumeneses, 2022-09-29:
Answering some:

- battery: Should be an estimate converted into percent (0 to 100). It will never be 100% (pun intended) accurate as the pin measures instantaneous battery voltage. Hence the values are passed only sporadically. One possible option is to pass only "high", "medium", and "low" as battery values. Also, changing batteries also changes max/min voltage values and requires manual tweaking of range
- brush and multibrush: it should not have a max/min as the theoretical ceiling is the sensor and function's refresh rate, which is higher than any human ca brush. The idea here is to have a type of gesture that is limited only by human capabilities rather than a hard coded limit
- count: people can count and map this in interesting ways. E.g., you keep taping and at the end it generates sound based on how high the count went, or can be used to jump to different sections, etc.
- double and triple tap: those are interesting Puara gestures, but since we're using the double tap to enter deep sleep, maybe they should not be exposed. to be discussed. Also, people can use count to extract any number of taps from buttons
- jab: works fine on the green T-Stick I have here, maybe we can expose some sensitivity parameters?
- multirub (and rub): you're referring to the range right? I think it outputs only positive values, so we only need to fix the range of the libmapper signal (also, should not be a ceiling, just like brush)
- tap, triple tap: I would only create a tap signal (check my double/triple tap answer)
- accel: AFAIK, it outputs m/s^2 (please check the comments at https://github.com/IDMIL/T-Stick/blob/master/firmware/src/lsm9ds1.h). In a discussion with @malloch, we agreed we should output "real-life" units as much as possible. So we have uTesla, radians per second, and m/s^2 for the IMU. The math could be double-checked as I made those pseudo-libraries more than 4 years ago.
- capsense: "another normalized centroid signal" means you want to add an extra gestural descriptor? If I understood correctly,I think what you want is already given by `touch.All`. It gives you a float between 0 and 1 according to the "amount of touch". Now, if you want a positional value, we could add this to the [Puara.gestures](https://github.com/Puara/puara-gestures) library
- fsr: sure, why not a normalized signal? It's already there (`getNormValue()` at [fsr.h](https://github.com/IDMIL/T-Stick/blob/master/firmware/src/fsr.h)/.cpp). Just replace the function at [main.cpp](https://github.com/IDMIL/T-Stick/blob/master/firmware/src/main.cpp) line 413.
- mag: "values stay around zero" has probably something to do with the units (It should be uTeslas), so I would start checking at the unit conversion or if we have a filter. If we plan to work on the sensor fusion soon, it might be a good time to check those units as we need to input them correctly at the functions

aburt2, 2022-10-05:
@edumeneses Is there a way for the tinypico to automatically change those ranges for battery life, it is a pain when fixing t-sticks that I can't trust the battery life signal to give me an accurate value

edumeneses, 2022-10-05:
Not that I know. The max and min voltage values depend on the battery.

What we can do is maybe measure the voltage of the battery from empty to full and back to empty a couple of times (+ with different batteries) and plot a profile for it. Then we can apply the profile to get a more accurate percentage, or maybe have 3 or 4 different levels.

DocSunset, 2022-10-05:
> Is there a way for the tinypico to automatically change those ranges for battery life, it is a pain when fixing t-sticks that I can't trust the battery life signal to give me an accurate value

In principle, if we wanted to have an accurate battery life estimate, we would need specific battery hardware (a fuel gauge I think it's called) in order to accurately measure the electrical current while charging and discharging.

DocSunset, 2022-10-13:
I notice there seem to be some issues with the accel range on my recently updated T-Stick (thanks again for that edu). The device correctly outputs 9.8 m/s^2 when stationary, reflecting approximately 1 g of acceleration as expected. So the math scaling from the raw readout of the sensor to m/s^2 is good. However, the following observations conflict:
- When shaken vigorously along one axis to try to saturate the sensor, it outputs almost exactly ±19.6 m/s^2, or 2 g
- In [`main.cpp:109`](https://github.com/IDMIL/T-Stick/blob/db5db96958b0cc35d567e9623f4d9122b5e7fa7b/firmware/src/main.cpp#L190) the min/max for libmapper is ±50 m/s^2, which would be 5.1 and some change g.
- In [`lsm9ds1.cpp:71`](https://github.com/IDMIL/T-Stick/blob/db5db96958b0cc35d567e9623f4d9122b5e7fa7b/firmware/src/lsm9ds1.cpp#L71) it appears as though the full scale range for the sensor should be 16 g, or 156.8 m/s^2

DocSunset, 2022-10-13:
There's a similar story with the gyro:
- the data output saturates at about ±5
- the stated range is ±25 rad/s (1432 deg/s)
- the supposed scale is 2000 deg/s (34.9 rad/s)

edumeneses, 2022-10-14:
This is most likely a problem with the SparkFunLSM9DS1 library. I put a note to myself at https://github.com/IDMIL/T-Stick/blob/db5db96958b0cc35d567e9623f4d9122b5e7fa7b/firmware/src/lsm9ds1.h (lines 3-6) referring to this known bug: https://github.com/sparkfun/SparkFun_LSM9DS1_Arduino_Library/issues/27

A possible workaround is to follow my note and manually change the SparkFunLSM9DS1.cpp file. I believe can also be done permanently using platformio.ini and python to create a script to edit the file during compilation.

Another possible solution is to clone the library and hardcode the sensitivity values, we can then refer to our clone at the [platformio.ini](https://github.com/IDMIL/T-Stick/blob/db5db96958b0cc35d567e9623f4d9122b5e7fa7b/firmware/platformio.ini) file. Of course, we can also properly fix their init function and open a PR to upstream our fix.

As I'm currently focusing on the MPU image, I can't check that right now, but the workarounds should work fine.

edumeneses, 2022-11-02:
Thanks, @DocSunset, to replace the IMU library. Suppose it honours the user settings we have at the [lsm9ds1.cpp](https://github.com/IDMIL/T-Stick/blob/master/firmware/src/lsm9ds1.cpp#L27) file, I suggest we close this issue and open a specific one for the battery reading if needed.

All other values are explained in my [message above](https://github.com/IDMIL/T-Stick/issues/10#issuecomment-1262327145). If needed, I also suggest opening another issue to change the range values for libmapper.

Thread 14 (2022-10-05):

Upgrade Capsense solution

aburt2, 2022-10-05:
Improve on the current capacitive sensor solution of the T-Stick with the aim to improve the spatial resolution, speed, reliability  of the capsense

DocSunset, 2022-10-05:
This could also synergise well with #15

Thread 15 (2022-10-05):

Improve Fabrication Process of T-Stick

aburt2, 2022-10-05:
Lower the difficulty and time required to assemble a T-Stick

- [ ] Simplify Touch sensor Assembly
- [ ] PCB Design for fabrication
- [ ] Switch away from Shrink tubing
- [ ] Easier access to components for maintenance

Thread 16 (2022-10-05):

Improve battery management of T-Stick

aburt2, 2022-10-05:
- [ ] Better feedback for when a T-Stick is on/off
- [ ] better battery state feedback (current signal is unreliable and requires manual tuning when battery is replaced)
- [ ] replaceable batteries

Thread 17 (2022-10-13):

Connection Guide Updates Required

DocSunset, 2022-10-13:
The [connection guide](https://github.com/IDMIL/T-Stick/blob/master/Docs/T-Stick_2GW_Connecting_Guide(v1.2).md) doesn't necessarily reflect the details of newer wireless T-Sticks. The differences are not especially problematic or significant, but it does create an unsettling feeling as I set up the T-Stick on my desk.

- My T-Stick has no power switch. How am I meant to power it on?
- If my battery is dead, how will I know?
- My T-Stick's setup network SSID is very different from the one shown (TStick_312 vs T-Stick_SN_black2_194).
- The setup webpage did not open automatically on my (unusually configured Arch Linux) device.consistent/simpler method that could be suggested.
- The design of the configuration page has changed and doesn't reflect the screen captures
- The T-Stick appears not to automatically switch over to the configured network and needs to be rebooted now?

I managed to figure it all out, and I've made some edits to the connection guide to help anyone after, but a more formal update may be in order, by someone who knows what's going on...

aburt2, 2022-11-07:
honestly I recon we should try to write the guides to use a little pictures as humanly possible @edumeneses I can do the updates as I've also been writing a connection guide for Torquetuner as there both Puara devices the steps are the same

edumeneses, 2022-11-08:
I agree @aburt2 !

I'll be at IDMIL this morning. We can talk about that and also about using Puara at TorqueTuner.

aburt2, 2023-04-19:
connection guide has been updated

Closed 2023-04-19.

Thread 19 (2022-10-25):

fsr offset bug

takujin3, 2022-10-25:
The problem is that it returns a negative value once you set the offset value. Clip the value.

DocSunset, 2022-11-01:
It would be helpful on this and other issues if you could describe why this is a problem. There may be deeper underlying issues and more efficient solutions, but we may not be able to tell if you merely suggest a solution without describing the problem.

aburt2, 2022-11-07:
The OSC signal for raw FSR isn't being properly calculated in the current firmware, for some reason it is outputting the raw value - offset which it did not use to do in previous versions

aburt2, 2023-11-08:
resolved with #27

Closed 2023-11-08.

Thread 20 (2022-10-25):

button bug

takujin3, 2022-10-25:
The button namespace outputs both 0 and 1 at the same time when I release the button. It is supposed to output only 1.

aburt2, 2025-09-01:
Button debouncing has been fixed, in the latest firmware.

Closed 2025-09-01.

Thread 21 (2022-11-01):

ypr namespace is wrong

takujin3, 2022-11-01:
r and y are inverted

DocSunset, 2022-11-01:
perhaps slightly off topic, but arguably yaw/pitch/roll is an inappropriate mental model for the T-Stick. It's not an aircraft. We use altitude/azimuth with the mubone, and latitude/longitude are also options. The last rotation (about the long axis of the tube) is less clear to me what you would call it, and for that matter whether you could use it for anything in the first place.

What are these orientation-related features called in older namespaces for the T-Stick? I remember having a patch with "tilt" for the altitude angle.

malloch, 2022-11-01:
Older T-Sticks (pre-magnetometer) used `instrument/tilt` and `instrument/roll`, both reported in degrees. Once the magnetometer was added we used `instrument/orientation/tilt`, `instrument/orientation/roll`, `instrument/orientation/heading`, and `instrument/orientation/quaternion`. Everything other than the quaternion was reported in radians, and the driver allows adding an arbitrary offset to the `heading` signal since most T-Stickists were interested in venue-relative coordinates.

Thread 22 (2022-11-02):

failure mode handling could generally be more graceful

DocSunset, 2022-11-02:
When one of the I2C sensors is having connection difficulties, the entire device becomes inoperable, without any indication of what's wrong. This makes it difficult to tell when something is amiss, since the behavior is almost the same as a dead battery.

Ideally, when one of the sensors in inaccessible, the firmware should detect this, report it in some fashion (e.g. set all the sensor values to NaN? Or perhaps there should be status signals that can be set appropriately if a problem is detected?), and move on to trying to do the rest of the work that the T-Stick usually does, like reading all the other sensors.

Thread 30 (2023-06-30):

Possible License Issue

DocSunset, 2023-06-30:
It appears the T-Stick firmware is marked as MIT licensed, whereas libmapper-arduino uses the stronger copyleft, and therefore incompatible, GPL 3+. I've left an issue on the latter in case this was not intended to be so (https://github.com/mathiasbredholt/libmapper-arduino/issues/11), but in case it is the T-Stick firmware probably needs to be changed to also use the GPL 3+ license. @edumeneses I'm guessing the MIT license here was inherited from the Puara template?

edumeneses, 2023-07-03:
Thanks for pointing that out @DocSunset.

The MIT portion mentioned in the [README](https://github.com/IDMIL/T-Stick#readme) comes from before Puara, but for the firmware folder, we have an inherited [LICENSE file](https://github.com/IDMIL/T-Stick/blob/main/firmware/LICENSE) from the Puara template.

But the [puara-module-template](https://github.com/Puara/puara-module-template) license is also wrong, as it loads Mathias' [libmapper-arduino](https://github.com/mathiasbredholt/libmapper-arduino). Finally,  [Puara-module](https://github.com/Puara/puara-module) states that it requires libmapper-arduino, but it doesn´t.

I'll fix the licensing on Puara's end: change the [puara-module-template](https://github.com/Puara/puara-module-template) to GPL3 and update the readme file for [Puara-module](https://github.com/Puara/puara-module), leaving it as MIT.

After that, we can fix the T-Stick's licence (should be GPL3).

I think we previously discussed the licensing for libmapper and decided to go for GPL3. Not sure if that's the best option **if** we want to spread libmapper usage beyond the open source, but this is a topic for the libmapper group.

DocSunset, 2023-07-03:
It seems like libmapper-arduino might get a license change (https://github.com/mathiasbredholt/libmapper-arduino/issues/11) so it might be better to wait for that situation to fully resolve. 👍

edumeneses, 2023-07-03:
Ah, I see. In that case, if Mathias decides to change to LGPL, we can keep MIT.

I might change Puara's licences to LGPL soon. I'll follow up and wait a bit to update the licenses all at once when libmapper-arduino license is sorted out.

DocSunset, 2023-09-25:
Mathias updated the upstream license to LGPL (mathiasbredholt/libmapper-arduino@54060796d08fe81d888958f7c023df5a5ffad720), so looks like this is a non-issue.

Closed 2023-09-25.

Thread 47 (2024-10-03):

Path collision

VincentCusson, 2024-10-03:
I get this error when git cloning on intel based MacOS Ventura 13.0.

```
warning: the following paths have collided (e.g. case-sensitive paths
on a case-insensitive filesystem) and only one from the same
colliding group is in the working tree:

  '3D_printing/bed_tinypico_USBC.stl'
  '3D_printing/bed_tinypico_usbc.stl'
```

Closed 2025-09-01.

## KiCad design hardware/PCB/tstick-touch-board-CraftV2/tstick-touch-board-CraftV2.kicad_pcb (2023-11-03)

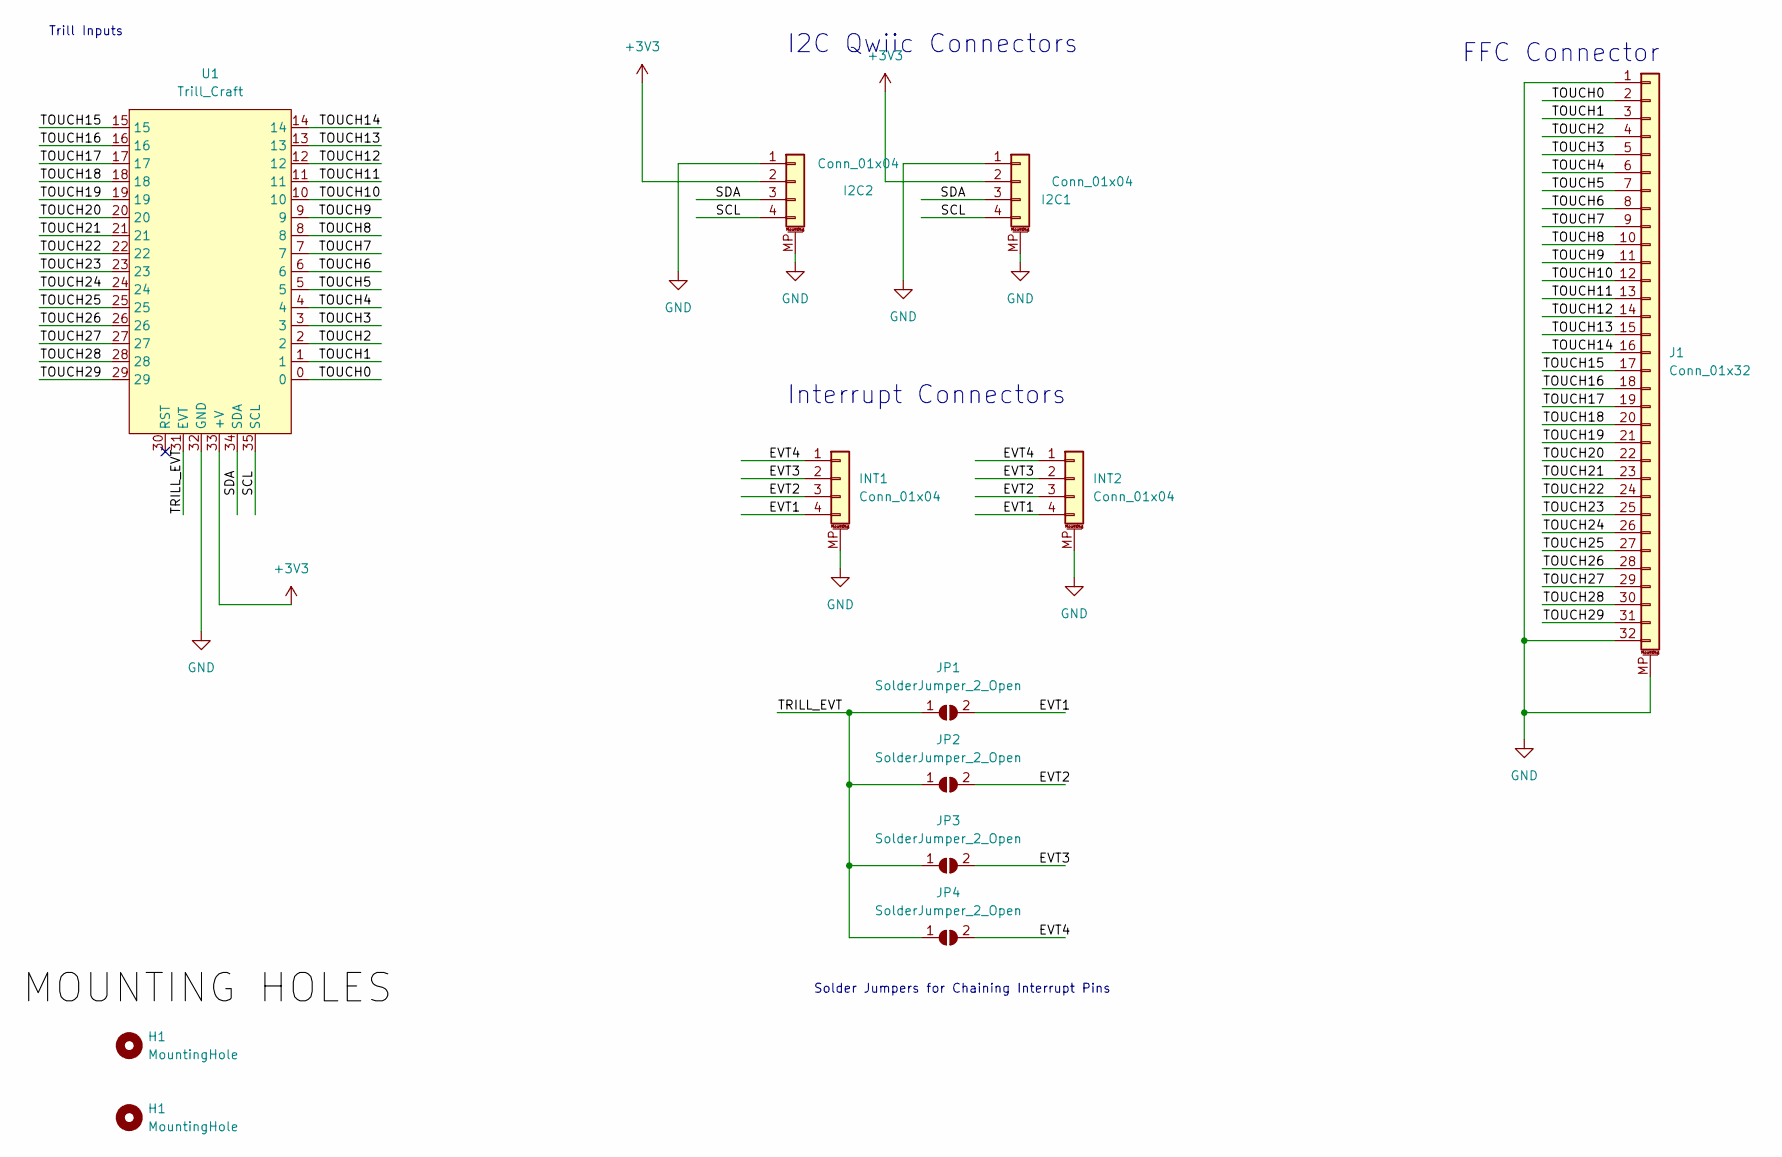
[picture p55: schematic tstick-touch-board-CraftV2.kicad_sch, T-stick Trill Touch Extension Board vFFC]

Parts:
H1: MountingHole; MountingHole_3.2mm_M3_DIN965
I2C1, I2C2: Conn_01x04; JST_SH_BM04B-SRSS-TB_1x04-1MP_P1.00mm_Vertical; Mfg Part # BM04B-SRSS-TB
INT1, INT2: Conn_01x04; JST_SH_BM04B-SRSS-TB_1x04-1MP_P1.00mm_Vertical; Mfg Part # BM04B-SRSS-TB
J1: Conn_01x32; CON_541323262_MOL; Mfg Part # 0541323262
JP1, JP2, JP3, JP4: SolderJumper_2_Open; SolderJumper-2_P1.3mm_Open_RoundedPad1.0x1.5mm
U1: Trill_Craft; Trill-Craft-Headers

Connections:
+3V3: I2C1.2, I2C2.2, U1.33 (+V)
/EVT1: INT1.4, INT2.4, JP1.2 (B)
/EVT2: INT1.3, INT2.3, JP2.2 (B)
/EVT3: INT1.2, INT2.2, JP3.2 (B)
/EVT4: INT1.1, INT2.1, JP4.2 (B)
/SCL: I2C1.4, I2C2.4, U1.35 (SCL)
/SDA: I2C1.3, I2C2.3, U1.34 (SDA)
/TOUCH0: J1.2, U1.0
/TOUCH1: J1.3, U1.1
/TOUCH2: J1.4, U1.2
/TOUCH3: J1.5, U1.3
/TOUCH4: J1.6, U1.4
/TOUCH5: J1.7, U1.5
/TOUCH6: J1.8, U1.6
/TOUCH7: J1.9, U1.7
/TOUCH8: J1.10, U1.8
/TOUCH9: J1.11, U1.9
/TOUCH10: J1.12, U1.10
/TOUCH11: J1.13, U1.11
/TOUCH12: J1.14, U1.12
/TOUCH13: J1.15, U1.13
/TOUCH14: J1.16, U1.14
/TOUCH15: J1.17, U1.15
/TOUCH16: J1.18, U1.16
/TOUCH17: J1.19, U1.17
/TOUCH18: J1.20, U1.18
/TOUCH19: J1.21, U1.19
/TOUCH20: J1.22, U1.20
/TOUCH21: J1.23, U1.21
/TOUCH22: J1.24, U1.22
/TOUCH23: J1.25, U1.23
/TOUCH24: J1.26, U1.24
/TOUCH25: J1.27, U1.25
/TOUCH26: J1.28, U1.26
/TOUCH27: J1.29, U1.27
/TOUCH28: J1.30, U1.28
/TOUCH29: J1.31, U1.29
/TRILL_EVT: JP1.1 (A), JP2.1 (A), JP3.1 (A), JP4.1 (A), U1.31 (EVT)
GND: I2C1.1, I2C1.MP (MountPin), I2C2.1, I2C2.MP (MountPin), INT1.MP (MountPin), INT2.MP (MountPin), J1.1, J1.32, J1.MP (MountPin), U1.32 (GND)

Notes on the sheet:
Trill Inputs
Interrupt Connectors
Solder Jumpers for Chaining Interrupt Pins
I2C Qwiic Connectors
FFC Connector

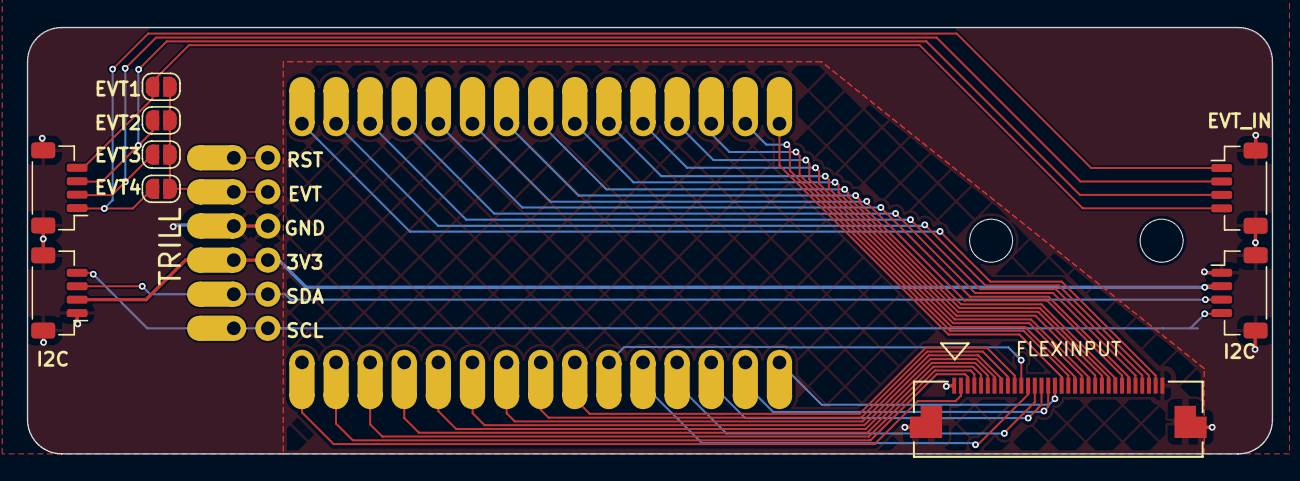
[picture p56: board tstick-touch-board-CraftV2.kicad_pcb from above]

Board: 2 copper layers, 92.7 x 31.8 mm, 12 parts (0 on the bottom side), 39 nets.

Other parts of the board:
H2: MountingHole; MountingHole_3.2mm_M3_DIN965

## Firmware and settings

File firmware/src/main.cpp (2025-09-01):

//****************************************************************************//
// T-Stick - sopranino/soprano firmware                                       //
// SAT/Metalab                                                                //
// Input Devices and Music Interaction Laboratory (IDMIL), McGill University  //
// Edu Meneses (2022) - https://www.edumeneses.com                            //
//****************************************************************************//

/* Created using the Puara template: https://github.com/Puara/puara-module-template 
 * The template contains a fully commented version for the commonly used commands 
 */


unsigned int firmware_version = 240401;
#define DEBUG
/*
Include T-Stick properties
- Go to tstick-presets.h to edit properties for your T-Stick
*/ 
#include "tstick-presets.h"

#include "Arduino.h"
#include "time.h"
// For JTAG monitor
#include "USB.h"

// For disabling power saving
#include "esp_wifi.h"

#include <puara.h>
#include <imu_orientation.h>
#include <puara_gestures.h>
#include <mapper.h>
#include <charconv>
#include <lo/lo.h>
#include <lo/lo_lowlevel.h>
#include <lo/lo_types.h>

#include <deque>
#include <cmath>
#include <algorithm>
#include <numeric>

// initializing libmapper, puara, puara-gestures, and liblo client
mpr_dev lm_dev = 0;
Puara puara;
PuaraGestures gestures;
lo_address osc1;
lo_address osc2;
std::string baseNamespace = "/";
std::string oscNamespace;
bool use_osc1 = false;
bool use_osc2 = false;

///////////////////////////
// Calibration Structure //
///////////////////////////
// struct calibrationParameters {
//     // Accelerometer Parameters
//     float accel_zerog[3];

//     // Gyroscope Parameters
//     float gyro_zerorate[3];
    
//     // Magnetometer Parameters
//     float sx[3];
//     float sy[3];
//     float sz[3];
//     float h[3];
// };
float accel_zerog[3];
float gyro_zerorate[3];
float sx[3];
float sy[3];
float sz[3];
float h[3];

calibrationParameters imuParams;

/////////////////////
// Pin definitions //
/////////////////////

struct TSTICK_Pin {
    int led;
    int battery;
    int fsr;
    int button;
};

TSTICK_Pin pin{ LED_PIN, 35, FSR_PIN, BUTTON_PIN };

////////////////////////////////
// Sensor Events //
////////////////////////////////

struct Event {
    bool shake = false;
    bool jab = false;
    bool count = false;
    bool tap = false;
    bool dtap = false;
    bool ttap = false;
    bool brush = false;
    bool rub = false;
    bool mimu = false;
    bool touchReady = false;
    bool battery = false;
    bool current = false;
    bool voltage = false;
    bool tte = false;
} event;


//////////////////////////////////
// Battery struct and functions //
//////////////////////////////////
struct BatteryData {
    float percentage = 0;
    float voltage = 0;
    float current = 0;
    float TTE = 0;
    bool status = false; // is there a battery
    uint16_t rsense = 0;
    float capacity = 0;
    uint16_t designcap = 0;
    float value;
    unsigned long timer = 0;
    int interval = 5000; // in ms (1/f)
    int queueAmount = 10; // # of values stored
    std::deque<int> filterArray; // store last values
} battery;

// read battery level (based on https://www.youtube.com/watch?v=yZjpYmWVLh8&feature=youtu.be&t=88) 
void analogBatteryRead() {
    #ifdef ARDUINO_LOLIN_D32_PRO
        battery.value = analogRead(pin.battery) / 4096.0 * 7.445;
    #elif defined(ARDUINO_TINYPICO)
        battery.value = tinypico.GetBatteryVoltage();
    #endif
    battery.percentage = static_cast<int>((battery.value - 2.9) * 100 / (4.15 - 2.9));
    if (battery.percentage > 100)
        battery.percentage = 100;
    if (battery.percentage < 0)
        battery.percentage = 0;
}

void batteryFilter() {
    battery.filterArray.push_back(battery.percentage);
    if(battery.filterArray.size() > battery.queueAmount) {
        battery.filterArray.pop_front();
    }
    battery.percentage = 0;
    for (int i=0; i<battery.filterArray.size(); i++) {
        battery.percentage += battery.filterArray.at(i);
    }
    battery.percentage /= battery.filterArray.size();
}

///////////////////////////////////
// Custom Interrupt Routines     //
///////////////////////////////////
void buttton_isr() {
    button.readButton();
}

void imu_isr() {
    event.mimu = true;
}

//////////////////////////////////////////////
// Include Touch stuff                      //
//////////////////////////////////////////////

// Touch arrays 
int mergedtouch[TSTICK_SIZE]; 
int mergeddiscretetouch[TSTICK_SIZE]; 
int mergednormalisedtouch[TSTICK_SIZE]; 

////////////////////////////////
// Include LED function files //
////////////////////////////////

struct Led_variables {
    int ledValue = 0;
    uint8_t color = 0;
} led_var;

//////////////////////
// Liblo OSC server //
//////////////////////

void error(int num, const char *msg, const char *path) {
    printf("Liblo server error %d in path %s: %s\n", num, path, msg);
    fflush(stdout);
}
lo_server_thread osc_server;

int generic_handler(const char *path, const char *types, lo_arg ** argv,
                    int argc, lo_message data, void *user_data) {
    for (int i = 0; i < argc; i++) {
        printf("arg %d '%c' ", i, types[i]);
        lo_arg_pp((lo_type)types[i], argv[i]);
        printf("\n");
    }
    printf("\n");
    fflush(stdout);

    return 1;
}

void osc_bundle_add_int(lo_bundle puara_bundle,const char *path, int value) {
    int ret = 0;
    oscNamespace.replace(oscNamespace.begin()+baseNamespace.size(),oscNamespace.end(), path);
    lo_message tmp_osc = lo_message_new();
    ret = lo_message_add_int32(tmp_osc, value);
    if (ret < 0) {
        lo_message_free(tmp_osc);
        return;
    }
    ret = lo_bundle_add_message(puara_bundle, oscNamespace.c_str(), tmp_osc);
    if(ret < 0) {
        std::cout << "error adding message to bundle" << std::endl;
    }
}
void osc_bundle_add_float(lo_bundle puara_bundle,const char *path, float value) {
    int ret = 0;
    oscNamespace.replace(oscNamespace.begin()+baseNamespace.size(),oscNamespace.end(), path);
    lo_message tmp_osc = lo_message_new();
    ret = lo_message_add_float(tmp_osc, value);
    if (ret < 0) {
        lo_message_free(tmp_osc);
        return;
    }
    ret = lo_bundle_add_message(puara_bundle, oscNamespace.c_str(), tmp_osc);
    if(ret < 0) {
        std::cout << "error adding message to bundle" << std::endl;
    }
}
void osc_bundle_add_int_array(lo_bundle puara_bundle,const char *path, int size, int *value) {
    oscNamespace.replace(oscNamespace.begin()+baseNamespace.size(),oscNamespace.end(), path);
    lo_message tmp_osc = lo_message_new();
    for (int i = 0; i < size; i++) {
        lo_message_add_int32(tmp_osc, value[i]);
    }
    lo_bundle_add_message(puara_bundle, oscNamespace.c_str(), tmp_osc);
}

void osc_bundle_add_float_array(lo_bundle puara_bundle,const char *path, int size,  float *value) {
    oscNamespace.replace(oscNamespace.begin()+baseNamespace.size(),oscNamespace.end(), path);
    lo_message tmp_osc = lo_message_new();
    for (int i = 0; i < size; i++) {
        lo_message_add_float(tmp_osc, value[i]);
    }
    lo_bundle_add_message(puara_bundle, oscNamespace.c_str(), tmp_osc);
}

////////////////////////////////
// sensors and libmapper data //
////////////////////////////////

struct Lm { 
    mpr_sig fsr = 0;  // FSR signals
    int fsrMax = 4095;
    int fsrMin = 0;
    mpr_sig squeeze = 0;
    float squeezeMax = 1.0f;
    float squeezeMin = 0.0f;
    mpr_sig accel = 0; // IMU signals
    float accelMax[3] = {50, 50, 50};
    float accelMin[3] = {-50, -50, -50};
    mpr_sig gyro = 0;
    float gyroMax[3] = {25, 25, 25};
    float gyroMin[3] = {-25, -25, -25};
    mpr_sig magn = 0;
    float magnMax[3] = {25, 25, 25};
    float magnMin[3] = {-25, -25, -25};
    mpr_sig quat = 0;
    float quatMax[4] = {1, 1, 1, 1};
    float quatMin[4] = {-1, -1, -1, -1};
    mpr_sig ypr = 0;
    float yprMax[3] = {M_PI, M_PI_2, M_PI};
    float yprMin[3] = {-M_PI, -M_PI_2, -M_PI};
    mpr_sig shake = 0;
    float shakeMax[3] = {100, 100, 100};
    float shakeMin[3] = {0, 0, 0};
    mpr_sig jab = 0;
    float jabMax[3] = {50, 50, 50};
    float jabMin[3] = {-50, -50, -50};
    mpr_sig touchAll = 0; // Touch signals
    mpr_sig touchTop = 0;
    mpr_sig touchMiddle = 0;
    mpr_sig touchBottom = 0;
    float touchgestureMax = 1.0f;
    float touchgestureMin = 0.0f;
    mpr_sig brush = 0;
    mpr_sig multibrush = 0;
    float brushMax[4] = {50, 50, 50, 50};
    float brushMin[4] = {-50, -50, -50, -50};
    mpr_sig rub = 0;
    mpr_sig multirub = 0;
    float rubMax[4] = {5, 5, 5, 5};
    float rubMin[4] = {0, 0, 0, 0};
    mpr_sig rawtouch = 0;
    int touchMax[TSTICK_SIZE]; // Initialized in setup()
    int touchMin[TSTICK_SIZE];
    mpr_sig count = 0; // Button Signals
    int countMax = 100;
    int countMin = 0;
    mpr_sig tap = 0;
    mpr_sig ttap = 0;
    mpr_sig dtap = 0;
    int tapMax = 1;
    int tapMin = 0;
    mpr_sig soc = 0; // Battery signals
    int batSOCMax = 100;
    int batSOCMin = 0;
    mpr_sig batvolt = 0;
    float batVoltMax = 4.2f;
    float batVoltMin = 0.0f;
    mpr_sig batcurr = 0;
    float batCurrMax = 2000.0f;
    float batCurrMin = -2000.0f;
    mpr_sig battte = 0;
    float battteMax = 102.0f;
    float battteMin = 0.0f;
    mpr_sig counter = 0;
    int counterMax = 80000;
    int counterMin = 0;
    mpr_sig looptime = 0;
    int timeMax = 1000000;
    int timeMin = 0;
} lm;
int use_libmapper = 0;

struct Sensors {
    float accl [3];
    float gyro [3];
    float magn [3];
    float quat [4];
    float ypr [3];
    float shake [3];
    float jab [3];
    float brush;
    float rub;
    float multibrush [4];
    float multirub [4];
    int count;
    int tap;
    int dtap;
    int ttap;
    int fsr;
    float squeeze;
    float battery;
    float current;
    float voltage;
    float tte;
    float touchAll;         
    float touchTop;         
    float touchMiddle;      
    float touchBottom;      
    int mergedtouch[TSTICK_SIZE];
    int mergeddiscretetouch[TSTICK_SIZE];
    int counter;
    int looptime;
} sensors;

// Debug code
// Timers
uint32_t start = 0;
uint32_t end = 0;
uint32_t time_taken = 0;

// task callbacks
// Comms tasks
void updateLibmapper();
void updateOSC();
void updateOSC_bundle(lo_bundle puara_bundle);

// Sensor callbacks
void readIMU();
void readTouch();
void readAnalog();
void readBattery();
void changeLED();
void updateMIMU();

// Define callbacks
///// Comms
void updateLibmapper() {
    mpr_dev_poll(lm_dev, 0);
    mpr_sig_set_value(lm.fsr, 0, 1, MPR_INT32, &sensors.fsr);
    mpr_sig_set_value(lm.accel, 0, 3, MPR_FLT, &sensors.accl);
    mpr_sig_set_value(lm.gyro, 0, 3, MPR_FLT, &sensors.gyro);
    mpr_sig_set_value(lm.magn, 0, 3, MPR_FLT, &sensors.magn);
    mpr_sig_set_value(lm.quat, 0, 4, MPR_FLT, &sensors.quat);
    mpr_sig_set_value(lm.ypr, 0, 3, MPR_FLT, &sensors.ypr);
    mpr_sig_set_value(lm.squeeze, 0, 1, MPR_FLT, &sensors.squeeze);
    mpr_sig_set_value(lm.shake, 0, 3, MPR_FLT, &sensors.shake);
    mpr_sig_set_value(lm.jab, 0, 3, MPR_FLT, &sensors.jab);
    mpr_sig_set_value(lm.rub, 0, 1, MPR_FLT, &sensors.rub);
    mpr_sig_set_value(lm.brush, 0, 1, MPR_FLT, &sensors.brush);
    mpr_sig_set_value(lm.multirub, 0, 4, MPR_FLT, &sensors.multirub);
    mpr_sig_set_value(lm.multibrush, 0, 4, MPR_FLT, &sensors.multibrush);
    mpr_sig_set_value(lm.count, 0, 1, MPR_INT32, &sensors.count);
    mpr_sig_set_value(lm.tap, 0, 1, MPR_INT32, &sensors.tap);
    mpr_sig_set_value(lm.ttap, 0, 1, MPR_INT32, &sensors.dtap);
    mpr_sig_set_value(lm.dtap, 0, 1, MPR_INT32, &sensors.ttap);
    mpr_sig_set_value(lm.soc, 0, 1, MPR_INT32, &sensors.battery);
    mpr_sig_set_value(lm.batvolt, 0, 1, MPR_FLT, &sensors.voltage);
    mpr_sig_set_value(lm.batcurr, 0, 1, MPR_FLT, &sensors.current);
    mpr_sig_set_value(lm.battte, 0, 1, MPR_FLT, &sensors.tte);
    mpr_sig_set_value(lm.rawtouch, 0, TSTICK_SIZE, MPR_INT32, &sensors.mergedtouch);
    mpr_sig_set_value(lm.touchAll, 0, 1, MPR_FLT, &sensors.touchAll);
    mpr_sig_set_value(lm.touchTop, 0, 1, MPR_FLT, &sensors.touchTop);
    mpr_sig_set_value(lm.touchMiddle, 0, 1, MPR_FLT, &sensors.touchMiddle);
    mpr_sig_set_value(lm.touchBottom, 0, 1, MPR_FLT, &sensors.touchBottom);
    mpr_sig_set_value(lm.counter, 0, 1, MPR_INT32, &sensors.counter);
    mpr_sig_set_value(lm.looptime, 0, 1, MPR_INT32, &sensors.looptime);
    mpr_dev_update_maps(lm_dev);
}

void updateOSC() {
    // Create a bundle and send it to both IP addresses
    if (use_osc1 || use_osc2) {
        lo_bundle bundle = lo_bundle_new(LO_TT_IMMEDIATE);
        if (!bundle) {
            return;
        }
        updateOSC_bundle(bundle);

        if (use_osc1) {
            lo_send_bundle(osc1, bundle);
        }
        if (use_osc2) {
            lo_send_bundle(osc2, bundle);
        }

        // free memory from bundle
        lo_bundle_free_recursive(bundle);
    }
}

void updateOSC_bundle(lo_bundle bundle) {
    // Continuously send FSR data
    osc_bundle_add_int(bundle, "raw/fsr", sensors.fsr);
    osc_bundle_add_float(bundle, "instrument/squeeze", sensors.squeeze);

    //Send touch data
    osc_bundle_add_float(bundle, "instrument/touch/all", sensors.touchAll);
    osc_bundle_add_float(bundle, "instrument/touch/top", sensors.touchTop);
    osc_bundle_add_float(bundle, "instrument/touch/middle", sensors.touchMiddle);
    osc_bundle_add_float(bundle, "instrument/touch/bottom", sensors.touchBottom);
    osc_bundle_add_int_array(bundle, "instrument/touch/discrete", TSTICK_SIZE, sensors.mergeddiscretetouch);
    osc_bundle_add_int_array(bundle, "raw/capsense", TSTICK_SIZE, sensors.mergedtouch);
    
    // Touch gestures
    if (event.brush) {
        osc_bundle_add_float(bundle, "instrument/brush", sensors.brush);
        osc_bundle_add_float_array(bundle, "instrument/multibrush", 4, sensors.multibrush);
    }
    if (event.rub) {
        osc_bundle_add_float(bundle, "instrument/rub", sensors.rub);
        osc_bundle_add_float_array(bundle, "instrument/multirub", 4, sensors.multirub);
    }

    
    // MIMU data
    osc_bundle_add_float_array(bundle, "raw/accl", 3, sensors.accl);
    osc_bundle_add_float_array(bundle, "raw/gyro", 3, sensors.gyro);
    osc_bundle_add_float_array(bundle, "raw/magn", 3, sensors.magn);
    osc_bundle_add_float_array(bundle, "orientation", 4, sensors.quat);
    osc_bundle_add_float_array(bundle, "ypr", 3, sensors.ypr); 

    // Inertial gestures
    if (event.shake) {
        osc_bundle_add_float_array(bundle, "instrument/shakexyz", 3, sensors.shake);
    }
    if (event.jab) {
        osc_bundle_add_float_array(bundle, "instrument/jabxyz", 3, sensors.jab);
    }
    // Button Gestures
    if (event.count) {
        osc_bundle_add_int(bundle, "instrument/button/count", sensors.count);
    }
    if (event.tap) {
        osc_bundle_add_int(bundle, "instrument/button/tap", sensors.tap);
    }
    if (event.dtap) {
        osc_bundle_add_int(bundle, "instrument/button/dtap", sensors.dtap);
    }
    if (event.ttap) {
        osc_bundle_add_int(bundle, "instrument/button/ttap", sensors.ttap);
    }

    // Battery Data
    if (event.battery) {
        osc_bundle_add_float(bundle, "battery/percentage", sensors.battery);
    }
    if (event.current) {
        osc_bundle_add_float(bundle, "battery/current", sensors.current);
    }
    if (event.tte) {
        osc_bundle_add_float(bundle, "battery/timetoempty", sensors.tte);
    }
    if (event.voltage) {
        osc_bundle_add_float(bundle, "battery/voltage", sensors.voltage);  
    }

    // Add counter
    osc_bundle_add_int(bundle, "test/counter", sensors.counter);
    osc_bundle_add_int(bundle, "test/looptime", sensors.looptime);
}

// Sensor callbacks
void readIMU() {
    imu.getData();

    // Save data to puara gestures
    gestures.setAccelerometerValues(imu.accl[0],
                                    imu.accl[1],
                                    imu.accl[2]);
    gestures.setGyroscopeValues(imu.gyro[0],
                                imu.gyro[1],
                                imu.gyro[2]);
    gestures.setMagnetometerValues(imu.magn[0],
                                    imu.magn[1],
                                    imu.magn[2]);

    // Convert accel from g's to meters/sec^2
    sensors.accl[0] = gestures.getAccelX() * 9.80665;
    sensors.accl[1] = gestures.getAccelY() * 9.80665;
    sensors.accl[2] = gestures.getAccelZ() * 9.80665;
    // Convert gyro from degrees/sec to radians/sec
    sensors.gyro[0] = gestures.getGyroX() * M_PI / 180;
    sensors.gyro[1] = gestures.getGyroY() * M_PI / 180;
    sensors.gyro[2] = gestures.getGyroZ() * M_PI / 180;
    // Convert mag from Gauss to uTesla
    sensors.magn[0] = gestures.getMagX();
    sensors.magn[1] = gestures.getMagY();
    sensors.magn[2] = gestures.getMagZ();
}

void readTouch() {
    // Read Touch
    touch.readTouch();
    touch.cookData();

    // Store in arrays for sensing
    for (int i = 0; i < TSTICK_SIZE; ++i) {
        sensors.mergedtouch[i] = touch.touch[i];
        sensors.mergeddiscretetouch[i] = touch.discreteTouch[i];
    }

    // Update touch gestures
    gestures.updateTouchArray(sensors.mergeddiscretetouch,TSTICK_SIZE);
    sensors.touchAll = gestures.touchAll;
    sensors.touchTop = gestures.touchTop;
    sensors.touchMiddle = gestures.touchMiddle;
    sensors.touchBottom = gestures.touchBottom;

    // Update event structure
    if (sensors.brush != gestures.brush || sensors.multibrush[0] != gestures.multiBrush[0]) {
        sensors.brush = gestures.brush;
        sensors.multibrush[0] = gestures.multiBrush[0];
        sensors.multibrush[1] = gestures.multiBrush[1];
        sensors.multibrush[2] = gestures.multiBrush[2];
        sensors.multibrush[3] = gestures.multiBrush[3];
        event.brush = true;
    } else { event.brush = false; }
    if (sensors.rub != gestures.rub || sensors.multirub[0] != gestures.multiRub[0]) {
        sensors.rub = gestures.rub;
        sensors.multirub[0] = gestures.multiRub[0];
        sensors.multirub[1] = gestures.multiRub[1];
        sensors.multirub[2] = gestures.multiRub[2];
        sensors.multirub[3] = gestures.multiRub[3];
        event.rub = true;
    } else { event.rub = false; }
    
    if (touch.newData || event.touchReady) {
        event.touchReady = true;
        touch.newData = 0;
    }
}
    

void readAnalog() {
    // Update button
    gestures.updateTrigButton(button.getButton());
    
    // go to deep sleep if double press button
    if (gestures.getButtonDTap()){
        std::cout << "\nEntering deep sleep.\n\nGoodbye!\n" << std::endl;
        imu.sleep();

        #ifdef LDO2
            digitalWrite(LDO_PIN, LOW); // disable second LDO
        #endif
        delay(1000);
        esp_deep_sleep_start();
    }

    // Read FSR
    fsr.readFsr();

    // Update array
    sensors.fsr = fsr.getValue();
    sensors.squeeze = fsr.getNormValue();

    // Update LED
    changeLED();

    // Update button
    if (sensors.count != gestures.getButtonCount()) {sensors.count = gestures.getButtonCount(); event.count = true; } else { event.count = false; }
    if (sensors.tap != gestures.getButtonTap()) {sensors.tap = gestures.getButtonTap(); event.tap = true; } else { event.tap = false; }
    if (sensors.dtap != gestures.getButtonDTap()) {sensors.dtap = gestures.getButtonDTap(); event.dtap = true; } else { event.dtap = false; }
    if (sensors.ttap != gestures.getButtonTTap()) {sensors.ttap = gestures.getButtonTTap(); event.ttap = true; } else { event.ttap = false; }
}

void readBattery() {
    #ifdef fg_MAX17055
    // Read battery stats from fuel gauge
    fuelgauge.getBatteryData();

    // Store battery info
    battery.percentage = fuelgauge.rep_soc;
    battery.current = fuelgauge.rep_inst_current;
    battery.voltage = fuelgauge.rep_avg_voltage;
    battery.TTE = fuelgauge.rep_tte;
    battery.rsense = fuelgauge.rsense;
    battery.capacity = fuelgauge.rep_capacity;
    battery.status = fuelgauge.bat_status;
    #elif defined(fg_NONE)
        analogBatteryRead();
        batteryFilter();
    #endif

    // Save to sensors array
    if (sensors.battery != battery.percentage) {sensors.battery = battery.percentage; event.battery = true; } else { event.battery = false; }
    if (sensors.current != battery.current) {sensors.current = battery.current; event.current = true; } else { event.current = false; }
    if (sensors.tte != battery.TTE) {sensors.tte = battery.TTE; event.tte = true; } else { event.tte = false; }
    if (sensors.voltage != battery.voltage) {sensors.voltage = battery.voltage; event.voltage = true; } else { event.voltage = false; }

    // // Send battery data always (for debugging)
    #ifdef DEBUG
        event.battery = true;
        event.voltage = true;
        event.current = true;
        event.tte = true;
    #endif
}
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
void loop() {
    start = micros();
    // Read analog signals
    readAnalog();

    // Update Battery data
    if (millis() - battery.interval > battery.timer) {
      battery.timer = millis();
      readBattery();
    }

    // Get touch data
    readTouch();

    // Update MIMU data
    updateMIMU();

    // Add to counter
    #ifdef DEBUG
    sensors.counter = sensors.counter + 1;
    end = micros();
    sensors.looptime = end - start;
    #endif
    if (puara.get_StaIsConnected()) {
        // Update Libmapper and OSC
        if (use_libmapper) {
            updateLibmapper();
        }

        // Update OSC
        updateOSC();
    }
}

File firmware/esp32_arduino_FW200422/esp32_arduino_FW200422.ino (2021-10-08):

//********************************************************************************//
//  Sopranino T-Stick 2GW - LOLIN D32 PRO - USB -WiFi                             //
//  Input Devices and Music Interaction Laboratory (IDMIL)                        //
//  Created:  February 2018 by Alex Nieva                                         //
//            March 2020 by Edu Meneses - firmware version 200330 (2020/Mar/30)   //
//  Notes   : Based on test program for reading CY8C201xx using I2C               //
//            by Joseph Malloch 2011                                              //
//                                                                                //
//            Adapted to work with Arduino IDE 1.8.10 and T-Stick Sopranino 2GW   //
//********************************************************************************//

//**************************************************//
// WiFi32Manager - For use with ESP8266 or ESP32    //
//                                                  //
// Created originally for the T-Stick project:      //
// http://www-new.idmil.org/project/the-t-stick/    //
//                                                  //
// This code uses code (fork) of 3 other projects:  //
// https://github.com/kentaylor/WiFiManager         //
// https://github.com/tzapu/WiFiManager             //
// https://github.com/zhouhan0126/WIFIMANAGER-ESP32 //
//                                                  //
// Edu Meneses - IDMIL - Mar 2019                   //
//**************************************************//

//**************************************************//
// MIMU - Magnetometer + accelerometer + gyroscope  //
// orientation library                              //
//                                                  //
// https://github.com/DocSunset/MIMU                //
//                                                  //
//                                                  //
// Travis West - IDMIL - Oct 2019                   //
//**************************************************//


// READ ALL DEPENDENCIES AND OBSERVATIONS BEFORE UPLOAD !!!!!!!!
// ---- --- ------------ --- ------------ ------ ------ 
// ---- --- ------------ --- ------------ ------ ------ 


// IMPORTANT: You need to upload a file (data/config.json) into ESP32 filesystem. 
// Follow the instructions at https://github.com/me-no-dev/arduino-esp32fs-plugin

// Tested on Wemos Lolin D32 Pro

// DEPENDENCIES:
// esp32 board library (add url to preferences; install via board manager)
// esp8266 board library (add url to preferences; install via board manager)
// Wifi32Manager https://github.com/edumeneses/WiFi32Manager
// Adafruit_LSM9DS1 (library manager)
// ArduinoJSON - https://github.com/bblanchon/ArduinoJson (v6.14.1)
// OSC - https://github.com/CNMAT/OSC (v3.5.7)
// MIMU - https://github.com/DocSunset/MIMU
// Eigen - https://github.com/bolderflight/Eigen

//  OBS:
//  1-) Use esp32 1.0.4 or newer (https://github.com/espressif/arduino-esp32/releases).
//  2-) Also install ESP8266 board library even if you'll use the ESP32 (https://github.com/esp8266/Arduino)
//  3-) MINU library complains if you keep any IMU-related files other than MIMU_LSM9DS1.h and MIMU_LSM9DS1.cpp
//  4-) Board currently in use: LOLIN D32 PRO.


#include <FS.h>

#define ESP32 // define ESP8266 or ESP32 according to your microcontroller.
//#define TSTICK193; // define if flashing the T-Stick #193.

#if defined(ESP32)
#include "platforms/ESP32.h"
#elif defined(ESP8266)
#include "platforms/ESP8266.h"
#else
#error Missing platform.
#endif

#include <ArduinoJson.h>  // https://github.com/bblanchon/ArduinoJson

#include <WiFi32Manager.h> // https://github.com/edumeneses/WiFi32Manager
// already includes:
// Wifi.h or ESP8266WiFi.h (https://github.com/esp8266/Arduino)
// AND
// WebServer.h or ESP8266WebServer.h
// AND
// DNSServer.h

// https://github.com/CNMAT/OSC (v3.5.7)
#include <WiFiUdp.h>
#include <OSCMessage.h>
#include <OSCBundle.h>

#include <Wire.h>
#include <SPI.h>
#include <MIMU_LSM9DS1.h> // https://github.com/DocSunset/MIMU
                          // requires SparkFunLSM9DS1 library - https://github.com/sparkfun/SparkFun_LSM9DS1_Arduino_Library
#include <MIMUCalibrator.h>
#include <MIMUFusion.h>

#include<stdlib.h> //floats to string


//////////////////////////////////
//////////////////////////////////
// T-Stick Specific Definitions //
//////////////////////////////////
//////////////////////////////////

const int32_t firmware = 200330;

struct Tstick {
  int id;
  char type[4];
  char author[20];
  char color[20];
  char APpasswd[15];
  char lastConnectedNetwork[30];
  char lastStoredPsk[30];
  int32_t firmware;
  byte osc;
  char oscIP[2][17];
  int32_t oscPORT[2];
  byte libmapper;
  int16_t FSRoffset;
  byte touchMask[8];
  float abias[3];
  float mbias[3];
  float gbias[3];
  float acclcalibration[9];
  float magncalibration[9];
  float gyrocalibration[9];
} Tstick;

struct RawDataStruct {
  byte touch[8]; // /raw/capsense, i..., 0--255, ... (1 int per 8 capacitive stripes -- 8 bits)
  byte touchStrips[64];
  int fsr; // /raw/fsr, i, 0--4095
  int piezo; // /raw/piezo, i, 0--1023
  float accl[3]; // /raw/accl, iii, +/-32767 (integers)
  float gyro[3]; // /raw/gyro, fff, +/-34.90659 (floats)
  float magn[3]; // /raw/magn, fff, +/-32767 (integers)
  float raw[10]; // /raw (IMU data to be send to callibration app)
  float quat[4]; // /raw/quat, ffff, ?, ? ,? ,?
  float magAccl;
  float magGyro;
  float magMagn;
  byte buttonShort; // /raw/button/short, i, 0 or 1
  byte buttonLong; // /raw/button/long, i, 0 or 1
  byte buttonDouble; // /raw/button/double, i, 0 or 1
} RawData;

struct NormDataStruct {
  float fsr; // /norm/fsr, f, 0--1
  float piezo; // /norm/piezo, f, 0--1
  float accl[3]; // /norm/accl, fff, +/-1, +/-1, +/-1
  float gyro[3]; // /norm/gyro, fff, +/-1, +/-1, +/-1
  float magn[3]; // /norm/magn, fff, +/-1, +/-1, +/-1
} NormData;

struct LastStateDataStruct {
  int blobPos[4];
  int gyroArrayCounter;
  float gyroXArray[5];
  float gyroYArray[5];
  float gyroZArray[5];
} LastState;

struct InstrumentDataStruct {
  float touchAll; // /instrument/touch/all, f, 0--1
  float touchTop; // /instrument/touch/top, f, 0--1
  float touchMiddle; // /instrument/touch/middle, f, 0--1
  float touchBottom; // /instrument/touch/bottom, f, 0--1
  float brush; // /instrument/touch/brush, f, 0--? (~cm/s)
  float multiBrush[4]; // /instrument/touch/brush/multibrush, ffff, 0--? (~cm/s)
  float rub; // /instrument/touch/rub, f, 0--? (~cm/s)
  float multiRub[4]; // /instrument/touch/rub/multirub, ffff, 0--? (~cm/s)
  float ypr[3]; // /instrument/ypr, fff, +/-180, +/-90 ,+/-180 (degrees)
  float shakeXYZ[3]; // /instrument/shakexyz, fff, 0--?
  float jabXYZ[3]; // /instrument/jabxyz, fff, 0--?
} InstrumentData;

struct Capsense { 
  byte answer1, answer2;
} capsense;
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

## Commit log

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2020-02-19 Added button debouncing, fixed compiler warnings, added ypr to libmapper
    [OSC.ino, WiFi.ino, data.ino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]
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2020-04-29 Reverted to working TStick-idf
    [main.cpp]
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2021-10-15 trill sopranino instructions update
    [Trill_bed.stl]
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2022-01-20 fix fsr and capsense
    [main.cpp]
2022-03-22 new 3d print cap
    [cap-new-tinypico.stl]
2022-03-29 fixed osc sending when wifi not connected
    [main.cpp]
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2022-05-02 add stl model for microsusb cap
    [bed_tinypico_microusb.stl]
2022-05-02 added fixed usbc bed stl
    [bed_tinypico_usbc.stl]
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2022-09-29 remove old firmware copy
    [min_spiffs.csv]
2022-10-13 Update T-Stick_2GW_Connecting_Guide(v1.2).md
    I found that the configuration portal did not open automatically. I was able to determine the T-Stick's IP address and navigate to it directly, so I added the suggestion to do this in case the portal doesn't open.
2022-11-02 fixes accel/gyro range issues
    Partial fix for #10
    The issue sparkfun/SparkFun_LSM9DS1_Arduino_Library#27 is
    worked around by pulling CAP1Sup/Arduino_LSM9DS1, which has a fix
    applied, instead of Sparkfun's original (apparently unmaintained)
    library.
    I also made adjustments to the full scale ranges of the accelerometer
    and magnetometer based on my experimentation, with notes in the source
    code describing my reasoning.
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2022-11-05 fix imu scaling and axes
    [main.cpp]
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2022-12-01 remove imu axes reversals
    [main.cpp]
2022-12-06 a few range updates and fsr fix
    [main.cpp]
2023-05-04 removed freecad files from master branch
    [bed.FCStd, bed_tinypico_usbc.FCStd, cap_tinypico_microusb.FCStd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]
2023-09-13 add pcb to master branch
    [tstick-5gw-pro-BOM.csv]
2023-09-13 removed PCB designs from master branch
    [tstick-5gw-pro-BOM.csv]
2023-10-31 add PCB design files from PCB design branch
    [touch-sensor-horizontal.kicad_pcb, touch-sensor-horizontal.kicad_sch, tstick-5gw-pro-USB-V2-BOM.xlsx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]
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2023-11-01 removed duplicate unused footprint and symbol libraries
    [tstick-touch-board-CraftV2.kicad_sch]
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2023-11-08 fixed a comment for setting the touch size
    [main.cpp]
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2023-11-20 updated schematic text, updated firmware to be compatible with custom esp32 board
    [tstick-5gw-pro-USB-V2-pcb.kicad_sch]
2023-11-20 removed unneccessary variables from battery structure, added support for up to 4 trill boards (doesn't send over OSC yet)
    [main.cpp]
2023-11-20 updated pcb BOM, switched buttons to smaller 3x2mm buttons
    [tstick-5gw-pro-USB-V2-BOM.xlsx, tstick-5gw-pro-USB-V2-pcb.kicad_pcb, tstick-5gw-pro-USB-V2-pcb.kicad_sch]
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2023-11-21 fix monitor filters, use fill solid to set LED color
    [main.cpp]
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2023-11-21 updated board flash size, added button interrupt, removed serial print
    [tstick-5gw-pro-USB-V2-BOM.xlsx, tstick-5gw-pro-USB-V2-pcb.kicad_pcb, tstick-5gw-pro-USB-V2-pcb.kicad_sch]
2023-11-21 removed some LED code, updated schematic, removed choke resistor from both board and BOM
    [tstick-5gw-pro-USB-V2-BOM.xlsx, tstick-5gw-pro-USB-V2-pcb.kicad_pcb, tstick-5gw-pro-USB-V2-pcb.kicad_sch]
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2023-11-22 removed neopixel, changed BOM, added simple status LEDs
    [PCBWay_positions.csv, tstick-5gw-pro-USB-V2-BOM.xlsx, tstick-5gw-pro-USB-V2-pcb.kicad_pcb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]
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2023-11-23 Only sends OSC over 1 IP address by default, added class for accessing touch data from custom touch board, uses similar syntax to trill touch class
    [tstick-5gw-pro-USB-V2-pcb.kicad_sch]
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2023-11-23 fixed MIMU interrupts, fixed minor syntax error in touch.cpp
    [main.cpp]
2023-11-28 fixed syntax error, increased prescaler for trill
    [main.cpp]
2023-11-29 fixed deep sleep not working
    [main.cpp]
2023-11-29 removed unused fuel gauge thresholds, added jab thresholds
    [PCBWay_positions.csv, tstick-5gw-pro-USB-V2-BOM.xlsx, tstick-5gw-pro-USB-V2-pcb.kicad_pcb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]
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2023-11-30 updated touch sensor design to be at the end of the board, also has longer neck
    [touch-sensor-horizontal.kicad_pcb, touch-sensor-horizontal.kicad_sch]
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2023-11-30 added IMU calibration scripts
    [min_spiffs_no_OTA.csv]
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2023-12-01 updated touch sensor design to be a slider
    [touch-sensor-horizontal.kicad_pcb, touch-sensor-horizontal.kicad_sch]
2023-12-01 Added updated pcb manufacturing files
    [touch-sensor-horizontal.kicad_pcb]
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2023-12-03 extended length of slider back to 30cm
    [touch-sensor-horizontal.kicad_pcb, touch-sensor-horizontal.kicad_sch]
2023-12-03 added enchanti touch board schematics to repository
    [PCBWay_positions.csv, enchanti-touch-board-BOM.csv, enchanti-touch-board.kicad_pcb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]
2023-12-03 bumped up all package sizes from a minimum of 0201 to 0402
    [tstick-5gw-pro-USB-V2-pcb.kicad_pcb, tstick-5gw-pro-USB-V2-pcb.kicad_sch]
2023-12-05 finished routing for the new pcb layout, will review later
    [tstick-5gw-pro-USB-V2-pcb.kicad_pcb]
2023-12-05 finished verifying pcb routing, updated pcb silkscreen
    [tstick-5gw-pro-USB-V2-pcb.kicad_pcb]
2023-12-06 moved LEDs, to the front of the board, took new screenshots
    [tstick-5gw-pro-USB-V2-pcb.kicad_pcb, tstick-5gw-pro-USB-V2-pcb.kicad_sch]
2023-12-07 updated BOM with new passive components
    [PCBWay_positions.csv, tstick-5gw-pro-USB-V2-BOM.xlsx]
2023-12-10 increased PCB board length, updated LEDs
    [PCBWay_positions.csv, tstick-5gw-pro-USB-V2-BOM.xlsx, tstick-5gw-pro-USB-V2-pcb.kicad_pcb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]
2023-12-11 rename PCB files to enchantiS3, exposed SPI pins for touch board
    Renamed ESP32 board PCB files to EnchantiS3
    Exposed SPI pins for enchanti touch board
    Changed Aux touch board connector to two 4 pin JST SM connectors
    Updated Enchanti touch board BOM an manufacturing files
    [PCBWay_positions.csv, enchanti-touch-board-BOM.csv, enchanti-touch-board.kicad_pcb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]
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2023-12-12 fixed git ignore to only ignore backups folder and not the manufacturing files
    [enchantiS3-BOM.csv, enchantiS3.kicad_pcb, enchantiS3.kicad_sch]
2023-12-12 added git ignore fix to other kicad projects
2023-12-12 updated manufacturing files for touch sensor
    [touch-sensor-horizontal.kicad_pcb]
2023-12-12 updated stiffener area with feedback from manufacturer
    [touch-sensor-horizontal.kicad_pcb]
2023-12-17 finished re-organising sensor libraries, added callbacks for task scheduler, fixed syntax errors
    [main.cpp]
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2023-12-20 fixed syntax errors, removed old interrupt routine for touch sensor
    [main.cpp]
2023-12-29 fixed syntax and compilation errors, slowed down OSC to 50Hz for testing
    [main.cpp]
2023-12-29 updated imu interrupt pin on the schematic
    [enchantiS3.kicad_sch]
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2024-01-10 Updated touch sensor design for better fit with assembly, fixed small allignment issue with touch board
    [PCBWay_positions.csv, enchanti-touch-board.kicad_pcb, touch-sensor-horizontal.kicad_pcb]
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2024-01-13 fixed compile errors, added SPI interface to Enchanti touch board
    [main.cpp]
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2024-01-19 updated touch sensor files
    [touch-sensor-horizontal.kicad_pcb]
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2024-02-04 reorganised libraries, replaced t-stick-properties.h with t-stick-presets.h
    [main.cpp, tstick-presets.h]
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2024-02-04 removed unneed dependencies, fixed syntax issues
    [main.cpp]
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2024-02-06 simplify rev3 design to only add an extra regulator
    [PCBWay_positions.csv, enchantiS3-BOM.csv, enchantiS3.kicad_pcb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]
2024-02-07 updated enchantis3 board files, slowed down I2C clock
    [PCBWay_positions.csv, enchantiS3.kicad_pcb, enchantiS3.kicad_sch]
2024-02-07 update enchanti s3 pcb, cleaned up traces around fuel gauge
    [PCBWay_positions.csv, enchantiS3.kicad_pcb, enchantiS3.kicad_sch]
2024-02-08 remove multithreading for better stability, update version number
    [main.cpp, tstick-presets.h]
2024-02-09 changed to MAX17262 fuel gauge, removed unneeded part libraries
    [enchantiS3.kicad_pcb, enchantiS3.kicad_sch]
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2024-02-10 fixed wrong connection between fuel gauge and system load
    [PCBWay_positions.csv, enchantiS3.kicad_pcb, enchantiS3.kicad_sch]
2024-02-29 updated libmapper signals, updated touch libraries, updated config file
    added missing OSC signals to libmapper, default config file now disables osc2, updated touch libraries to use the same touch_config variable as an input, bumped firmware number
    [main.cpp, tstick-presets.h]
2024-03-01 fixed ranges for current and time to empty signals
    [main.cpp]
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2024-04-09 set booleans for using osc in the setup() to avoid crashes when changing IP settings
    [main.cpp]
2024-04-20 set current gain on startup for fuel gauge, properly compute touch noise
    [main.cpp]
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2025-09-01 re-remove enchantiS3 board files that were added due to merge
    [PCBWay_positions.csv, enchantiS3-BOM.csv, enchantiS3.kicad_pcb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]
